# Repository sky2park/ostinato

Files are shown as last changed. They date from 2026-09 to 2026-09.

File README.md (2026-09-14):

# Ostinato

[🇺🇸 English](docs/README.en.md)




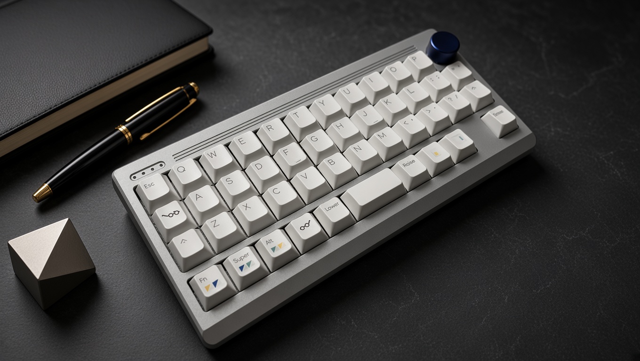
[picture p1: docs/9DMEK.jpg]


처음부터 직접 설계한 40% 오소리니어 기계식 키보드입니다.

Ostinato는 커스텀 PCB, 알루미늄 케이스, 가스켓 마운트 플레이트, 로터리 엔코더, RGB 상태 표시등, USB 연결을 기본으로 하는 45키 오소리니어 키보드입니다. USB 전원이 공급되는 상태에서 Bluetooth 무선 출력을 사용할 수 있습니다.

이 프로젝트에는 PCB와 케이스부터 QMK/Vial 펌웨어와 ESP32-C3 Bluetooth 컨트롤러까지 전체 하드웨어 및 펌웨어 설계가 포함되어 있습니다.

---

## 주요 기능

- 40% 오소리니어 레이아웃
- 45키
- MX 호환 스위치
- QMK 펌웨어
- Vial 지원
- USB 및 Bluetooth 연결
- ESP32-C3 기반 Bluetooth 컨트롤러 (USB 전원 필요, 배터리 없음, 단독 무선 작동 불가)
- RP2040 기반 메인 컨트롤러
- 3개의 Bluetooth 연결 슬롯
- 로터리 엔코더
- SK6812MINI RGB LED
- 전용 Bluetooth 상태 표시등
- 레이어 상태 표시
- 가스켓 마운트 플레이트
- 커스텀 알루미늄 상판 케이스
- MJF PA12S 나일론 하판 케이스
- SUS304 스테인리스 스틸 또는 H59 구리 합금 황동 내부 웨이트

---

## 사양

| 항목 | 내용 |
|---|---|
| 레이아웃 | 40% 오소리니어 |
| 키 수 | 45 |
| 메인 MCU | RP2040 |
| Bluetooth MCU | ESP32-C3 |
| 펌웨어 | QMK |
| 키맵 설정 | Vial |
| 연결 방식 | USB 기본 / Bluetooth 무선 출력 (USB 전원 필요) |
| 전원 공급 | USB |
| 배터리 | 없음 |
| Bluetooth 슬롯 | 3 |
| 스위치 종류 | MX 호환 |
| RGB LED | SK6812MINI (4개) |
| 로터리 엔코더 | 1개 |
| 마운팅 | 가스켓 마운트 (Poron) |
| 플레이트 | PC |
| 상판 케이스 | 6061 알루미늄 |
| 하판 케이스 | MJF PA12S 나일론 |
| 내부 웨이트 | SUS304 스테인리스 스틸 또는 H59 구리 합금 황동 |

---

## 레이아웃

Ostinato는 45키의 컴팩트한 40% 오소리니어 레이아웃을 사용합니다.

작은 크기를 유지하면서 풀사이즈 키보드에 준하는 기능을 제공할 수 있도록 여러 레이어를 중심으로 설계되었습니다.

### 레이어

펌웨어에는 다음과 같은 주요 레이어가 포함되어 있습니다:

- **기본**
- **내비게이션**
- **숫자 / 기호**
- **기능**
- **게이밍**
- **게이밍+**
- **게이밍 내비게이션**

추가 레이어와 키 할당은 Vial을 통해 설정할 수 있습니다.

---

## 연결

Ostinato는 USB 연결을 기본으로 사용하며, USB 전원이 공급되는 상태에서 Bluetooth 무선 출력을 지원합니다.

> **⚠️ 전원 및 Bluetooth 사용 안내**
>
> Ostinato는 배터리를 내장하지 않은 키보드입니다. 키보드의 작동과 Bluetooth 사용을 위해 USB 케이블을 연결해야 합니다.
>
> USB 케이블을 연결하지 않은 상태에서는 키보드 단독으로 Bluetooth를 사용할 수 없습니다.

RP2040은 키보드의 주요 기능을 담당하며, ESP32-C3 모듈이 Bluetooth 연결을 제공합니다.

### USB

USB 모드에서는 일반적인 USB HID 키보드로 동작합니다.

### Bluetooth

키보드는 3개의 Bluetooth 연결 슬롯을 지원합니다:

- **Bluetooth 1**
- **Bluetooth 2**
- **Bluetooth 3**

활성 Bluetooth 슬롯은 키보드에서 직접 선택할 수 있습니다. 펌웨어는 UART를 통해 ESP32-C3와 통신하며 Bluetooth 연결 상태와 슬롯 선택을 제어합니다.

Bluetooth를 사용하더라도 USB 케이블을 통한 전원 공급이 필요합니다. 배터리가 없으므로 USB 전원 없이 Bluetooth만으로 작동할 수 없습니다.

---

## Bluetooth 상태

RGB LED는 Bluetooth 상태를 시각적으로 표시하는 데 사용됩니다. 각 Bluetooth 슬롯에는 전용 상태 표시등이 있습니다.

표시등은 다음과 같은 상태를 구분합니다:

- 광고(Advertising)
- 연결됨
- 페어링
- 오류 / 사용 불가

이를 통해 호스트 기기를 사용하지 않고도 현재 Bluetooth 연결 상태를 확인할 수 있습니다.

---

## RGB 표시등

Ostinato는 4개의 SK6812MINI RGB LED를 사용합니다. 이 LED는 장식용 백라이트가 아니라 기능적인 상태 표시등으로 사용됩니다.

### Bluetooth 표시등

3개의 LED가 각각 3개의 Bluetooth 슬롯 상태를 표시합니다.

### 레이어 표시등

나머지 1개의 LED는 레이어/상태 표시용으로 사용됩니다. 펌웨어는 이 표시등을 특수 키보드 기능의 상태를 표시하는 데에도 사용할 수 있습니다.

---

## 로터리 엔코더

Ostinato에는 추가 입력을 위한 로터리 엔코더가 포함되어 있습니다.

엔코더는 QMK와 Vial을 통해 설정할 수 있으며, 활성 레이어에 따라 서로 다른 기능을 할당할 수 있습니다.

---

## 아키텍처 및 설계 철학

Ostinato의 목표는 컴팩트한 오소리니어 레이아웃에 일반적으로 대형 키보드에서 제공되는 기능을 결합하는 것입니다.

하나의 무선 컨트롤러에 모든 기능을 의존하는 대신, 메인 키보드 컨트롤러와 Bluetooth 컨트롤러를 분리하는 구조로 설계했습니다:

```text
       ┌───────────────┐
       │    RP2040     │
       │ Main Keyboard │
       │  Controller   │
       └───────┬───────┘
               │
              UART
               │
       ┌───────▼───────┐
       │   ESP32-C3    │
       │   Bluetooth   │
       │  Controller   │
       └───────────────┘
```

이 아키텍처를 통해 RP2040은 핵심 키보드 동작(매트릭스 스캔, 조명, Vial 설정)을 담당하고, ESP32-C3는 Bluetooth 연결 스택을 담당합니다.

---

## 펌웨어

Ostinato 펌웨어는 QMK 및 Vial-QMK를 기반으로 하며 **GNU General Public License v2.0 (GPL-2.0)**에 따라 라이선스가 부여됩니다.

```text
firmware/
├── esp32-c3/
├── qmk/
│   └── ostinato/
└── vial/
    └── ostinato/
```

- **QMK 펌웨어**: 매트릭스 스캔, 키맵 및 레이어, 커스텀 키코드, 로터리 엔코더, RGB 상태 표시등, USB 출력, ESP32-C3와의 UART 통신을 담당합니다.
- **ESP32-C3 펌웨어**: Bluetooth 프로파일 관리, 연결 슬롯, 무선 HID 출력을 담당합니다.

### 커스텀 키코드

Ostinato는 출력 및 연결 제어를 위해 다음과 같은 커스텀 키코드를 정의합니다:

- `OUT_USB`
- `OUT_BT1`
- `OUT_BT2`
- `OUT_BT3`
- `BT_CLR`

이 키코드를 사용하면 USB와 페어링된 3개의 Bluetooth 기기 사이를 즉시 전환할 수 있습니다.

---

## 하드웨어

PCB, 케이스, 플레이트 및 관련 CAD 파일을 포함한 Ostinato 하드웨어 설계 파일은 **Creative Commons Attribution-NonCommercial 4.0 International (CC BY-NC 4.0)** 라이선스에 따라 제공됩니다.

개인적 및 비상업적 사용은 허용됩니다.

상업적 사용에는 저작자의 사전 허가가 필요합니다.

하드웨어는 다음과 같은 모듈형 커스텀 보드로 구성됩니다:

```text
pcb/
├── main-module/
├── led_module/
└── knob-module/
```

- **메인 모듈**: RP2040 컨트롤러, ESP32-C3, 다이오드 매트릭스 및 전원 회로를 탑재합니다.
- **LED 모듈**: 슬롯 및 레이어 상태 표시를 위한 4개의 SK6812MINI 어드레서블 RGB LED를 탑재합니다.
- **노브 모듈**: 로터리 엔코더와 브레이크아웃 인터페이스를 탑재합니다.

### 케이스 및 플레이트

- **상판 케이스**: CNC 가공 6061 알루미늄
- **하판 케이스**: MJF 3D 프린팅 PA12S 나일론
- **내부 웨이트**: 레이저 절단 SUS304 스테인리스 스틸 또는 H59 구리 합금 황동
- **마운팅**: PC 플레이트를 분리하는 커스텀 Poron 가스켓 스트립을 사용하여 부드럽고 공명감 있는 바텀아웃을 구현합니다.

> **제조 및 공차 관련 참고사항**  
> 모든 케이스 부품(상판 케이스, 하판 케이스, 내부 웨이트)은 **JLCCNC** 및 **JLC3DP**를 통해 프로토타입을 제작하고 검증했습니다. 제조업체와 제작 방식에 따라 공차와 표면 마감이 달라질 수 있으므로, 다른 업체에서 제작한 부품은 테스트되지 않았으며 조립 또는 치수 호환성 문제가 발생할 수 있습니다.

플레이트 절단 프로파일은 `plate/` 아래에 DXF 형식으로 제공됩니다:
- `design.dxf`
- `plate.dxf`

---

## 제조 및 주문 가이드

모든 부품은 특정 제작 업체를 기준으로 설계하고 검증했습니다. Ostinato를 제작할 계획이라면 아래 주문 가이드를 참고하세요.

### 개요

| 부품 | 소스 파일 | 권장 서비스 | 공정 / 재료 사양 |
|---|---|---|---|
| **Top Case** | `case/top.step`<br>`case/top_theads.pdf` (Thread/tapping drawing) | JLCCNC | CNC Machining / 6061 Aluminum (Sandblasted / Anodized) |
| **Bottom Case** | `case/bottom.step` | JLC3DP | 3D Printing / MJF Nylon (PA12S) |
| **Internal Weight** | `case/weight.step` | JLCCNC | CNC or Sheet Metal / SUS304 Stainless steel or H59 Brass |
| **Plate** | `plate/plate.dxf` | Laser cutting service | Laser Cut / 1.5mm Polycarbonate (PC) |
| **PCBs** | `pcb/*/gerber/` | JLCPCB | FR-4 / 1.6mm (or 1.2mm depending on build) |

---

### 부품 상세 및 주문 방법

#### 1. 케이스 및 웨이트 (JLCCNC / JLC3DP)
- **Top Case**:
  - **File**: `case/top.step`
  - **나사산 도면**: `case/top_theads.pdf` (탭 가공을 주문할 때 이 2D 도면을 함께 첨부하세요)
  - **서비스**: [JLCCNC](https://jlccnc.com/) (CNC 가공)
  - **재료**: 6061 알루미늄
  - **표면 처리**: 비드 블라스트(샌드블라스트 #150 또는 #180) + 아노다이징(원하는 색상)
- **Bottom Case**:
  - **File**: `case/bottom.step`
  - **Service**: [JLC3DP](https://jlc3dp.com/) (3D Printing)
  - **기술**: MJF (Multi Jet Fusion)
  - **재료**: PA12S 나일론 (검정/염색)
- **Internal Weight**:
  - **File**: `case/weight.step`
  - **Service**: [JLCCNC](https://jlccnc.com/)
  - **재료**: SUS304 스테인리스 스틸 (헤어라인 / 샌드블라스트) 또는 H59 황동

> ⚠️ **중요 공차 경고**:  
> CAD 모델, 공차 및 조립 여유 치수는 **JLCCNC** 및 **JLC3DP**를 기준으로 조정하고 검증했습니다. 다른 업체나 다른 제작 방식은 테스트되지 않았으며, 부적절한 조립, 수축 편차 또는 조립 문제가 발생할 수 있습니다.

#### 2. 스위치 플레이트
- **File**: `plate/plate.dxf`
- **재료**: 1.5mm 폴리카보네이트 (PC)
- **서비스**: 정밀 레이저 절단이 가능한 업체 (예: JLCCNC 판재 절단 또는 현지 레이저 절단 업체).

#### 3. PCB
- **Paths**:
  - `pcb/main-module/`
  - `pcb/led_module/`
  - `pcb/knob-module/`
- **Service**: [JLCPCB](https://jlcpcb.com/)
- **Ordering Recommendations**:
  - Upload the Gerber zip files along with the **BOM and CPL files** from each folder to order the **PCB Assembly (SMT)** service.
  - **PCBA Settings**:
    - **Assembly Side**: Select **`Bottom Side`** for all three modules.
    - **PCBA Type**:
      - `main-module`: Must be set to **`Standard`** due to assembly constraints of the ESP32-C3 module (bottom pad soldering).
      - `led_module` & `knob-module`: Select **`Economy`**.
  - ⚠️ **Note**: The **EC11 rotary encoder** on the `knob-module` is not covered by the SMT service; source it separately and solder it by hand (through-hole soldering).
  
#### 4. 추가 기성 부품 (하드웨어 및 구매)

이러한 표준 하드웨어 부품과 구성품은 별도 제작품이 아니며, 일반 하드웨어 마켓플레이스(예: AliExpress)나 커스텀 키보드 판매처에서 구매할 수 있습니다.

> **참고**: 아래 링크는 제가 프로토타입 제작에 실제로 사용한 동일한 제품 목록과 구매처입니다. 참고용으로만 제공하며, 사양에 맞는 동등한 부품이라면 어떤 제품을 사용해도 됩니다.

| 품목 | 사양 | 수량 | 참고 링크 | 비고 |
|---|---|---|---|---|
| **Poron Gasket Strips** | 20mm (L) × 3mm (W) × 2mm (T) | 8 | [AliExpress](https://ko.aliexpress.com/item/1005005713921230.html) | Mounts to plate tabs / case edges |
| **FPC Ribbon Cable** | 0.5mm pitch, 6-pin, **Reverse (Type B)**, 10–15cm | 2 | [AliExpress](https://aliexpress.com/item/1005007862185591.html) | Connects main module to LED / knob modules |
| **Rotary Encoder** | EC11 rotary encoder, **15mm shaft height** | 1 | [AliExpress](https://aliexpress.com/item/1005009120433387.html) | Hand-soldered onto `knob-module` |
| **Encoder Knob** | Compatible with EC11 shaft **20 x 13 x 6mm** | 1 | [AliExpress](https://aliexpress.com/item/1005007339301144.html) | Fits selected rotary encoder |
| **Unified Daughterboard S1 & Cable** | Unified Daughterboard (UDB) S1 with Molex cable | 1 | [Vendor Link](https://keebd.com/products/unified-daughterboards?variant=45606739411096) | Available via various keyboard vendor stores (e.g., CannonKeys, Swagkeys, etc.)
| **Light Guides** | Acrylic light pipe / guide **1.5-2.2 or 2.9-3.0** | 4 | [AliExpress](https://aliexpress.com/item/1005005231503928.html) | Diffuses status LEDs |
| **Heat-set Insert** | M2 × L3mm × OD 3.2mm | 4 | [AliExpress](https://aliexpress.com/item/1005006472641726.html) | Case / module mounting |
| **Heat-set Insert** | M3 × L4mm × OD 4.2mm | 6 | [AliExpress](https://aliexpress.com/item/1005006472641726.html) | Weight / case and Weight / UDB mounting |
| **Screw** | M2 × 4mm | 4 | [AliExpress](https://aliexpress.com/item/1005005270702287.html) | Internal module mounting |
| **Screw** | M2.5 × 8mm | 4 | [AliExpress](https://aliexpress.com/item/1005005270702287.html) | Case assembly |
| **Screw** | M3 × 5mm | 6 | [AliExpress](https://aliexpress.com/item/1005005270702287.html) | Internal weight / UDB fastening |

---

## 빌드 가이드

🚧 상세 빌드 가이드 영상은 현재 준비 중입니다.

---

## 저장소 구조

```text
ostinato/
├── case/             # CAD and step/stl files for case parts
├── firmware/
│   ├── esp32-c3/     # ESP-IDF / Arduino BT firmware
│   ├── qmk/          # QMK source and keyboard rules
│   │   └── ostinato/
│   └── vial/         # Vial configuration & keymap files
│       └── ostinato/
├── pcb/
│   ├── main-module/  # Schematic, KiCad layouts, and Gerber files
│   ├── led_module/
│   └── knob-module/
├── plate/
│   ├── design.dxf
│   └── plate.dxf
└── README.md
```

---

## 상태

Ostinato는 현재 개발이 진행 중인 커스텀 하드웨어 프로젝트입니다. 실제 리비전을 테스트하는 과정에서 회로도, Gerber 파일 및 펌웨어 구현이 호환성을 깨뜨리는 형태로 변경될 수 있습니다.

---

## 크레딧

**sky2park**가 설계 및 개발했습니다.

- [QMK Firmware](https://qmk.fm/)
- [Vial](https://get.vial.today/)
- Raspberry Pi RP2040 & Espressif ESP32-C3

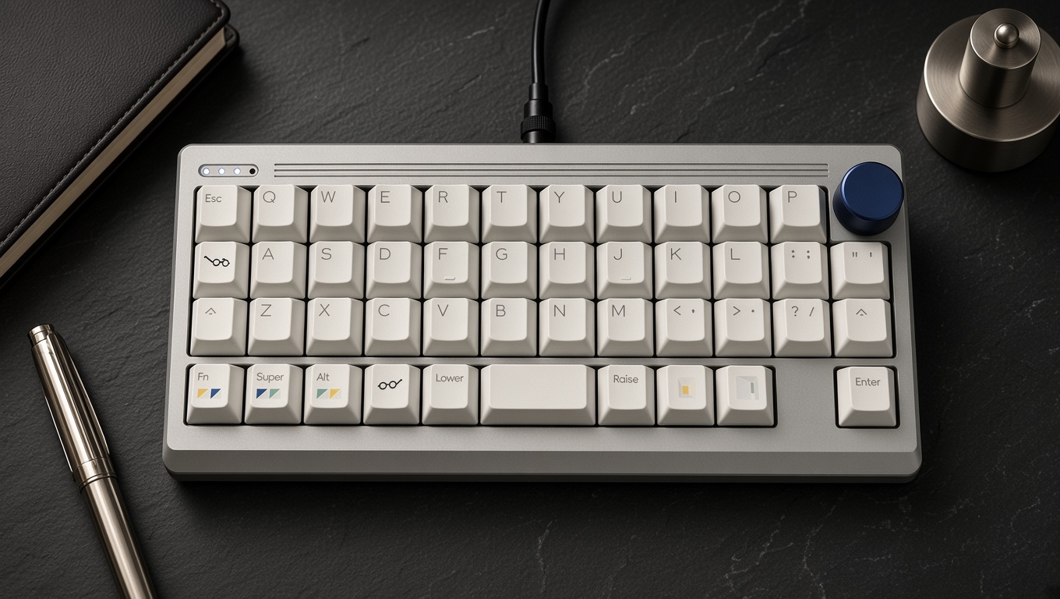
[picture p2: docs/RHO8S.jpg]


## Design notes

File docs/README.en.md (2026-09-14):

# Ostinato

[🇰🇷 한국어](../README.md)




Ostinato Keyboard

A custom 40% ortholinear mechanical keyboard designed from the ground up.

Ostinato is a custom 45-key ortholinear keyboard featuring a custom PCB, aluminum case, gasket-mounted plate, rotary encoder, RGB status indicators, and USB connectivity with Bluetooth wireless output when powered via USB.

The project includes the complete hardware and firmware design, from the PCB and case to the QMK/Vial firmware and ESP32-C3 Bluetooth controller.

---

## Features

- 40% ortholinear layout
- 45 keys
- MX-compatible switches
- QMK firmware
- Vial support
- USB and Bluetooth connectivity
- ESP32-C3-based Bluetooth controller (USB power required; no battery; standalone wireless operation is not supported)
- RP2040-based main controller
- Three Bluetooth connection slots
- Rotary encoder
- SK6812MINI RGB LEDs
- Dedicated Bluetooth status indicators
- Layer status indication
- Gasket-mounted plate
- Custom aluminum top case
- MJF PA12S nylon bottom case
- Stainless steel or H59 Copper alloy Brass internal weight

---

## Specifications

| Specification | Details |
|---|---|
| Layout | 40% Ortholinear |
| Keys | 45 |
| Main MCU | RP2040 |
| Bluetooth MCU | ESP32-C3 |
| Firmware | QMK |
| Keymap Configuration | Vial |
| Connectivity | USB (primary) / Bluetooth wireless output (USB power required) |
| Power | USB |
| Battery | None |
| Bluetooth Slots | 3 |
| Switch Type | MX-compatible |
| RGB LEDs | SK6812MINI (4x) |
| Rotary Encoder | 1 |
| Mounting | Gasket mount (Poron) |
| Plate | PC |
| Top Case | 6061 Aluminum |
| Bottom Case | MJF PA12S Nylon |
| Internal Weight | SUS304 Stainless steel or H59 Copper alloy Brass |

---

## Layout

Ostinato uses a compact 40% ortholinear layout with 45 keys.

The layout is designed around multiple layers to provide the functionality of a full-size keyboard while maintaining a small footprint.

### Layers

The firmware includes the following primary layers:

- **Base**
- **Navigation**
- **Number / Symbol**
- **Function**
- **Gaming**
- **Gaming+**
- **Gaming Navigation**

Additional layers and key assignments can be configured through Vial.

---

## Connectivity

Ostinato is primarily designed to operate with a USB connection. Bluetooth wireless output is available when the keyboard is powered via USB.

> **⚠️ Power and Bluetooth Notice**
>
> Ostinato does not have a built-in battery. A USB cable must be connected to power the keyboard.
>
> Bluetooth can only be used while USB power is connected. Standalone Bluetooth operation without a USB connection is not supported.

### USB

In USB mode, Ostinato operates as a standard USB HID keyboard. The keyboard is powered through the USB connection, and all primary functions are available.

### Bluetooth

In Bluetooth mode, the ESP32-C3 transmits key inputs wirelessly to a paired host device.

The keyboard supports three Bluetooth connection slots:

- Bluetooth 1
- Bluetooth 2
- Bluetooth 3

The active Bluetooth slot can be selected directly from the keyboard. The firmware communicates with the ESP32-C3 over UART to control Bluetooth connection status and slot selection.

**Note:** USB power is required even when using Bluetooth. Ostinato has no battery and cannot operate as a standalone wireless keyboard without a USB connection.

### USB

In USB mode, the keyboard operates as a standard USB HID keyboard.

### Bluetooth

The keyboard supports three Bluetooth connection slots:

- **Bluetooth 1**
- **Bluetooth 2**
- **Bluetooth 3**

The active Bluetooth slot can be selected directly from the keyboard. The firmware communicates with the ESP32-C3 over UART to control Bluetooth connection state and slot selection.

---

## Bluetooth Status

The RGB LEDs are used to provide visual feedback for Bluetooth status. Each Bluetooth slot has a dedicated status indicator.

The indicators distinguish between states such as:

- Advertising
- Connected
- Pairing
- Error / unavailable

This allows the current Bluetooth connection state to be checked without using a host device.

---

## RGB Indicators

Ostinato uses four SK6812MINI RGB LEDs. The LEDs are used as functional status indicators rather than decorative backlighting.

### Bluetooth Indicators

Three LEDs indicate the status of the three Bluetooth slots.

### Layer Indicator

The remaining LED is used for layer/status indication. The firmware can also use the indicator to display the state of special keyboard functions.

---

## Rotary Encoder

Ostinato includes a rotary encoder for additional input.

The encoder can be configured through QMK and Vial and can be assigned different functions depending on the active layer.

---

## Architecture & Design Philosophy

The goal of Ostinato is to combine a compact ortholinear layout with functionality normally associated with larger keyboards.

Rather than relying on a single wireless controller, the design separates the main keyboard controller and Bluetooth controller:

```text
       ┌───────────────┐
       │    RP2040     │
       │ Main Keyboard │
       │  Controller   │
       └───────┬───────┘
               │
              UART
               │
       ┌───────▼───────┐
       │   ESP32-C3    │
       │   Bluetooth   │
       │  Controller   │
       └───────────────┘
```

This architecture allows the RP2040 to remain responsible for the core keyboard operations (matrix scanning, lighting, Vial configuration) while the ESP32-C3 handles the Bluetooth connectivity stack.

---

## Firmware

The Ostinato firmware is based on QMK and Vial-QMK and is licensed under the **GNU General Public License v2.0 (GPL-2.0)**.

```text
firmware/
├── esp32-c3/
├── qmk/
│   └── ostinato/
└── vial/
    └── ostinato/
```

- **QMK Firmware**: Handles matrix scanning, keymaps and layers, custom keycodes, rotary encoder, RGB status indicators, USB output, and UART communication with the ESP32-C3.
- **ESP32-C3 Firmware**: Handles Bluetooth profile management, connection slots, and wireless HID output.

### Custom Keycodes

Ostinato defines custom keycodes for output and connection control:

- `OUT_USB`
- `OUT_BT1`
- `OUT_BT2`
- `OUT_BT3`
- `BT_CLR`

These keycodes allow switching between USB and the three paired Bluetooth devices on the fly.

---

## Hardware

The Ostinato hardware design files, including PCB, case, plate, and related CAD files, are licensed under the **Creative Commons Attribution-NonCommercial 4.0 International (CC BY-NC 4.0)** license.

Personal and non-commercial use is permitted.

Commercial use requires prior permission from the author.

The hardware is divided into modular custom boards:

```text
pcb/
├── main-module/
├── led_module/
└── knob-module/
```

- **Main Module**: Hosts the RP2040 controller, ESP32-C3, diode matrix, and power regulation.
- **LED Module**: Contains four SK6812MINI addressable RGB LEDs for slot and layer visualization.
- **Knob Module**: Houses the rotary encoder and its breakout interface.

### Case & Plate

- **Top Case**: CNC-machined 6061 aluminum
- **Bottom Case**: MJF 3D-printed PA12S nylon
- **Internal Weight**: Laser-cut SUS304 Stainless steel or H59 Copper alloy Brass
- **Mounting**: Custom Poron gasket strips isolating the PC plate for a soft, resonant bottom-out.

> **Note on Manufacturing & Tolerances**  
> All case components (top case, bottom case, and internal weight) were prototyped and verified using **JLCCNC** and **JLC3DP**. Because tolerances and finishing can vary across different manufacturers and fabrication methods, parts produced through other vendors have not been tested and may have fitment/assembly issues.

Plate cutting profiles are provided in DXF format under `plate/`:
- `design.dxf`
- `plate.dxf`

---

## Manufacturing & Ordering Guide

All components have been designed and verified with specific fabrication vendors. If you plan to build Ostinato, follow the guidelines below for ordering parts.

### Overview

| Part | Source Files | Recommended Service | Process / Material Specs |
|---|---|---|---|
| **Top Case** | `case/top.step`<br>`case/top_theads.pdf` (Thread/tapping drawing) | JLCCNC | CNC Machining / 6061 Aluminum (Sandblasted / Anodized) |
| **Bottom Case** | `case/bottom.step` | JLC3DP | 3D Printing / MJF Nylon (PA12S) |
| **Internal Weight** | `case/weight.step` | JLCCNC | CNC or Sheet Metal / SUS304 Stainless steel or H59 Brass |
| **Plate** | `plate/plate.dxf` | Laser cutting service | Laser Cut / 1.5mm Polycarbonate (PC) |
| **PCBs** | `pcb/*/gerber/` | JLCPCB | FR-4 / 1.6mm (or 1.2mm depending on build) |

---

### Component Details & Ordering Instructions

#### 1. Case & Weight (JLCCNC / JLC3DP)
- **Top Case**:
  - **File**: `case/top.step`
  - **Thread Drawing**: `case/top_theads.pdf` (Attach this 2D drawing when ordering for threaded hole tapping)
  - **Service**: [JLCCNC](https://jlccnc.com/) (CNC Machining)
  - **Material**: 6061 Aluminum
  - **Finish**: Bead blasted (Sandblasting #150 or #180) + Anodized (Color of your choice)
- **Bottom Case**:
  - **File**: `case/bottom.step`
  - **Service**: [JLC3DP](https://jlc3dp.com/) (3D Printing)
  - **Technology**: MJF (Multi Jet Fusion)
  - **Material**: PA12S Nylon (Black/Dyed)
- **Internal Weight**:
  - **File**: `case/weight.step`
  - **Service**: [JLCCNC](https://jlccnc.com/)
  - **Material**: SUS304 Stainless steel (Brushed / Sandblasted) or H59 Brass

> ⚠️ **Important Tolerance Warning**:  
> The CAD models, tolerances, and fitment clearances are tuned and verified specifically for **JLCCNC** and **JLC3DP**. Fabrication via other vendors or processes has not been tested and may result in improper fitment, shrinkage variance, or assembly issues.

#### 2. Switch Plate
- **File**: `plate/plate.dxf`
- **Material**: 1.5mm Polycarbonate (PC)
- **Service**: Any precision laser-cutting vendor (e.g., JLCCNC sheet cutting or local laser cutting services).

#### 3. PCBs
- **Paths**:
  - `pcb/main-module/`
  - `pcb/led_module/`
  - `pcb/knob-module/`
- **Service**: [JLCPCB](https://jlcpcb.com/)
- **Ordering Recommendations**:
  - Upload the Gerber zip files along with the **BOM and CPL files** from each folder to order the **PCB Assembly (SMT)** service.
  - **PCBA Settings**:
    - **Assembly Side**: Select **`Bottom Side`** for all three modules.
    - **PCBA Type**:
      - `main-module`: Must be set to **`Standard`** due to assembly constraints of the ESP32-C3 module (bottom pad soldering).
      - `led_module` & `knob-module`: Select **`Economy`**.
  - ⚠️ **Note**: The **EC11 rotary encoder** on the `knob-module` is not covered by the SMT service; source it separately and solder it by hand (through-hole soldering).
  
#### 4. Additional Off-the-Shelf Parts (Hardware & Sourcing)

These standard hardware parts and components are not custom-fabricated and can be sourced from general hardware marketplaces (e.g., AliExpress) or custom keyboard vendors.

> **Note**: The links below reflect the exact listings and sources I used for my prototype build. They are provided solely for reference—any equivalent parts matching the specifications will work.

| Item | Specification | Qty | Reference Link | Notes |
|---|---|---|---|---|
| **Poron Gasket Strips** | 20mm (L) × 3mm (W) × 2mm (T) | 8 | [AliExpress](https://ko.aliexpress.com/item/1005005713921230.html) | Mounts to plate tabs / case edges |
| **FPC Ribbon Cable** | 0.5mm pitch, 6-pin, **Reverse (Type B)**, 10–15cm | 2 | [AliExpress](https://aliexpress.com/item/1005007862185591.html) | Connects main module to LED / knob modules |
| **Rotary Encoder** | EC11 rotary encoder, **15mm shaft height** | 1 | [AliExpress](https://aliexpress.com/item/1005009120433387.html) | Hand-soldered onto `knob-module` |
| **Encoder Knob** | Compatible with EC11 shaft **20 x 13 x 6mm** | 1 | [AliExpress](https://aliexpress.com/item/1005007339301144.html) | Fits selected rotary encoder |
| **Unified Daughterboard S1 & Cable** | Unified Daughterboard (UDB) S1 with Molex cable | 1 | [Vendor Link](https://keebd.com/products/unified-daughterboards?variant=45606739411096) | Available via various keyboard vendor stores (e.g., CannonKeys, Swagkeys, etc.)
| **Light Guides** | Acrylic light pipe / guide **1.5-2.2 or 2.9-3.0** | 4 | [AliExpress](https://aliexpress.com/item/1005005231503928.html) | Diffuses status LEDs |
| **Heat-set Insert** | M2 × L3mm × OD 3.2mm | 4 | [AliExpress](https://aliexpress.com/item/1005006472641726.html) | Case / module mounting |
| **Heat-set Insert** | M3 × L4mm × OD 4.2mm | 6 | [AliExpress](https://aliexpress.com/item/1005006472641726.html) | Weight / case and Weight / UDB mounting |
| **Screw** | M2 × 4mm | 4 | [AliExpress](https://aliexpress.com/item/1005005270702287.html) | Internal module mounting |
| **Screw** | M2.5 × 8mm | 4 | [AliExpress](https://aliexpress.com/item/1005005270702287.html) | Case assembly |
| **Screw** | M3 × 5mm | 6 | [AliExpress](https://aliexpress.com/item/1005005270702287.html) | Internal weight / UDB fastening |

---

## Build Guide

A detailed build guide video is currently in preparation
and will be added here once available.

---

## Repository Structure

```text
ostinato/
├── case/             # CAD and step/stl files for case parts
├── firmware/
│   ├── esp32-c3/     # ESP-IDF / Arduino BT firmware
│   ├── qmk/          # QMK source and keyboard rules
│   │   └── ostinato/
│   └── vial/         # Vial configuration & keymap files
│       └── ostinato/
├── pcb/
│   ├── main-module/  # Schematic, KiCad layouts, and Gerber files
│   ├── led_module/
│   └── knob-module/
├── plate/
│   ├── design.dxf
│   └── plate.dxf
└── README.md
```

---

## Status

Ostinato is an active custom hardware project. Schematics, gerber files, and firmware implementations may receive breaking updates as physical revisions are tested.

---

## Credits

Designed and developed by **sky2park**.

- [QMK Firmware](https://qmk.fm/)
- [Vial](https://get.vial.today/)
- Raspberry Pi RP2040 & Espressif ESP32-C3

Ostinato Keyboard

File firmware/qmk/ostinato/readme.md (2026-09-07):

# Ostinato

Ostinato

*A short description of the keyboard/project*

* Keyboard Maintainer: [sky2park](https://github.com/sky2park)
* Hardware Supported: *The PCBs, controllers supported*
* Hardware Availability: *Links to where you can find this hardware*

Make example for this keyboard (after setting up your build environment):

    make ostinato:default

Flashing example for this keyboard:

    make ostinato:default:flash

See the [build environment setup](https://docs.qmk.fm/#/getting_started_build_tools) and the [make instructions](https://docs.qmk.fm/#/getting_started_make_guide) for more information. Brand new to QMK? Start with our [Complete Newbs Guide](https://docs.qmk.fm/#/newbs).

## Bootloader

Enter the bootloader in 3 ways:

* **Bootmagic reset**: Hold down the key at (0,0) in the matrix (usually the top left key or Escape) and plug in the keyboard
* **Physical reset button**: Briefly press the button on the back of the PCB - some may have pads you must short instead
* **Keycode in layout**: Press the key mapped to `QK_BOOT` if it is available

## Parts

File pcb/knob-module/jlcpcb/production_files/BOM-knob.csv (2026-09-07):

Comment | Designator | Footprint | LCSC | Quantity
Conn_01x06 | J1 | Hirose_FH12-6S-0.5SH_1x06-1MP_P0.50mm_Horizontal | C202118 | 1
D_Small | D47 | D_SOD-123 | C81598 | 1

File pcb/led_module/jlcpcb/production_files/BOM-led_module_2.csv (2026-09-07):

Comment | Designator | Footprint | LCSC | Quantity
100nF | C1,C2,C3,C4 | C_0402_1005Metric | C1525 | 4
10uF | C5 | C_0402_1005Metric | C15525 | 1
330 | R1 | R_0402_1005Metric | C21190 | 1
Conn_01x06 | J1 | Hirose_FH12-6S-0.5SH_1x06-1MP_P0.50mm_Horizontal | C202118 | 1
SK6812MINI-E | D1,D2,D3,D4 | LED_SK6812MINI-E_3.2x2.8mm_P1.5mm_ReverseMount | C5378731 | 4

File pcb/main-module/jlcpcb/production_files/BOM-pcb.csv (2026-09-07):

Comment | Designator | Footprint | LCSC | Quantity
100nF | C1,C10,C11,C12,C13,C14,C15,C19,C20,C5,C6,C9 | C_0402_1005Metric | C1525 | 12
10k | R10,R11,R3,R6,R7 | R_0402_1005Metric | C25744 | 5
10uF | C17,C18,C7 | C_0402_1005Metric | C15525 | 3
12MHz | Y1 | Crystal_SMD_3225-4Pin_3.2x2.5mm | C9002 | 1
1k | R1,R2 | R_0402_1005Metric | C11702 | 2
1uF | C16,C4,C8 | C_0402_1005Metric | C52923 | 3
220 | R8,R9 | R_0402_1005Metric | C25091 | 2
22pF | C2,C3 | C_0402_1005Metric | C1555 | 2
27R | R4,R5 | R_0402_1005Metric | C25100 | 2
AP2112K-3.3 | U2 | SOT-23-5 | C3021085 | 1
Conn_01x06 | J3,J4 | Hirose_FH12-6S-0.5SH_1x06-1MP_P0.50mm_Horizontal | C202118 | 2
D_Small | D1,D10,D11,D12,D13,D14,D15,D16,D17,D18,D19,D2,D20,D21,D22,D23,D24,D25,D26,D27,D28,D29,D3,D30,D31,D32,D33,D34,D35,D36,D37,D38,D39,D4,D40,D41,D42,D43,D44,D45,D5,D6,D7,D8,D9 | D_SOD-123 | C81598 | 45
ESP32-C3-MINI-1 | U4 | ESP32-C3-MINI-1 | C2838502 | 1
Molex - 1.00mm 4 Pin | J1,J2 | Molex_Pico-EZmate_78171-0004_1x04-1MP_P1.20mm_Vertical | C588524 | 2
RP2040 | U3 | RP2040-QFN-56 | C2040 | 1
SW_Push | SW_ESP_BOOTSEL1,SW_ESP_RESET1,SW_RP_BOOTSEL1,SW_RP_RESET1 | SW_SPST_TS-1088-xR020 | C720477 | 4
W25Q128JVS | U1 | SOIC-8_5.3x5.3mm_P1.27mm | C97521 | 1

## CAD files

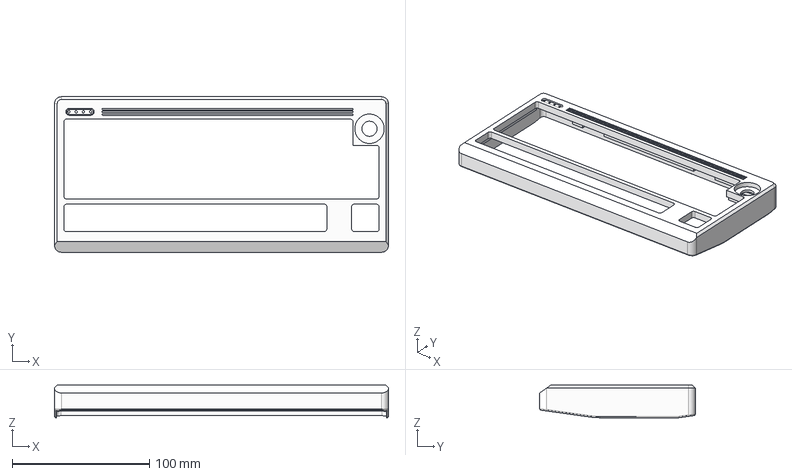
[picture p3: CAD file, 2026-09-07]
case/top.step
243.2 x 113.3 x 23.7 mm

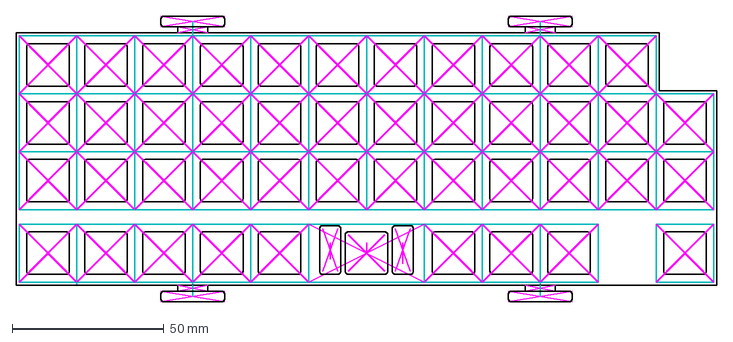
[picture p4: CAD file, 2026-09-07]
plate/design.dxf
230.6 x 94.0 mm

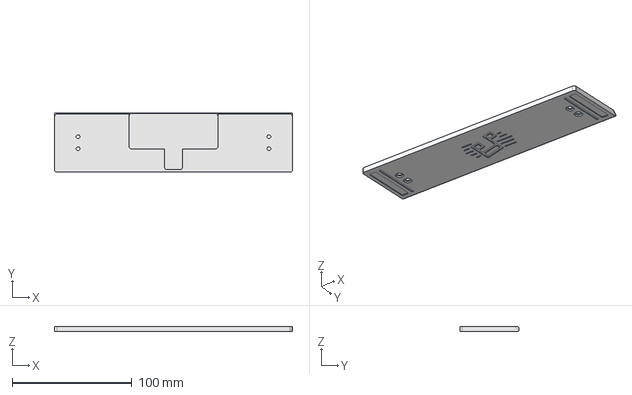
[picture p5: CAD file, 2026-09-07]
case/weight.step
199.0 x 49.7 x 4.00 mm

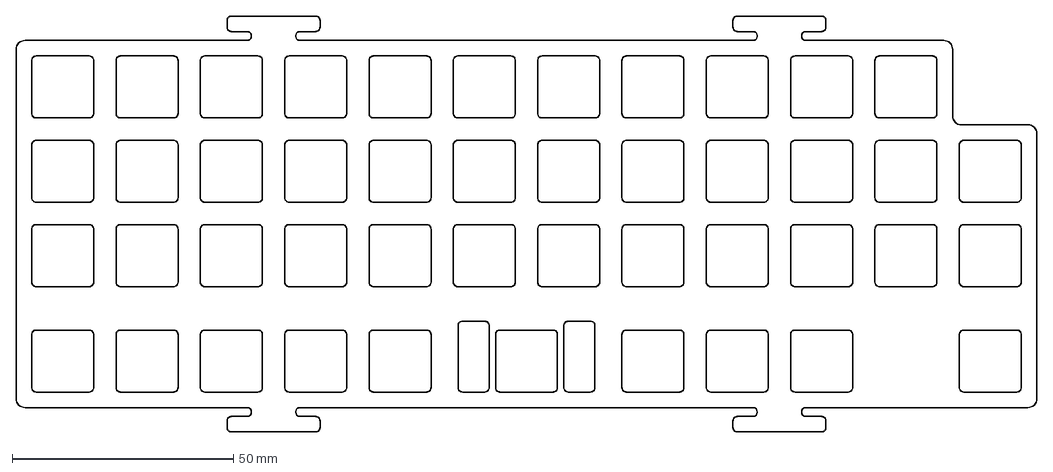
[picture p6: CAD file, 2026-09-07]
plate/plate.dxf
230.6 x 94.0 mm

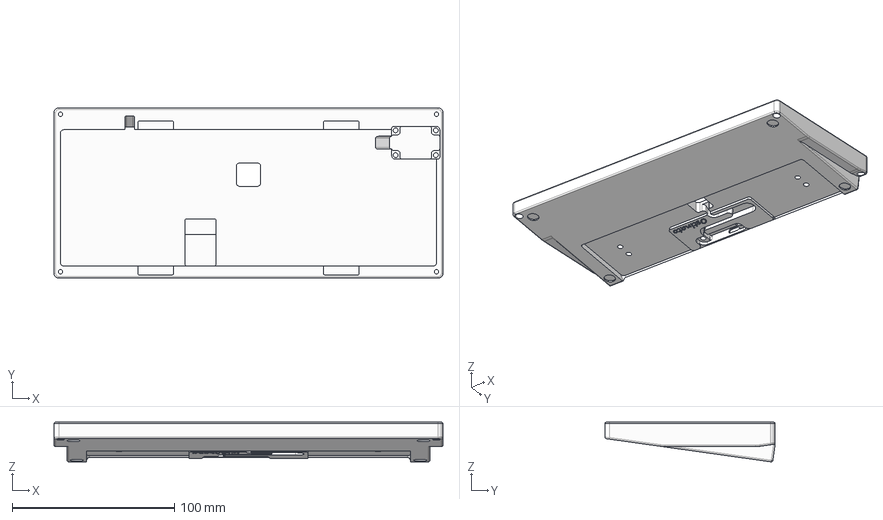
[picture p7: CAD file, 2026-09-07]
case/bottom.step
239.6 x 105.0 x 24.5 mm

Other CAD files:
case/f3d/bottom.f3d
case/f3d/top.f3d
case/f3d/weight.f3d

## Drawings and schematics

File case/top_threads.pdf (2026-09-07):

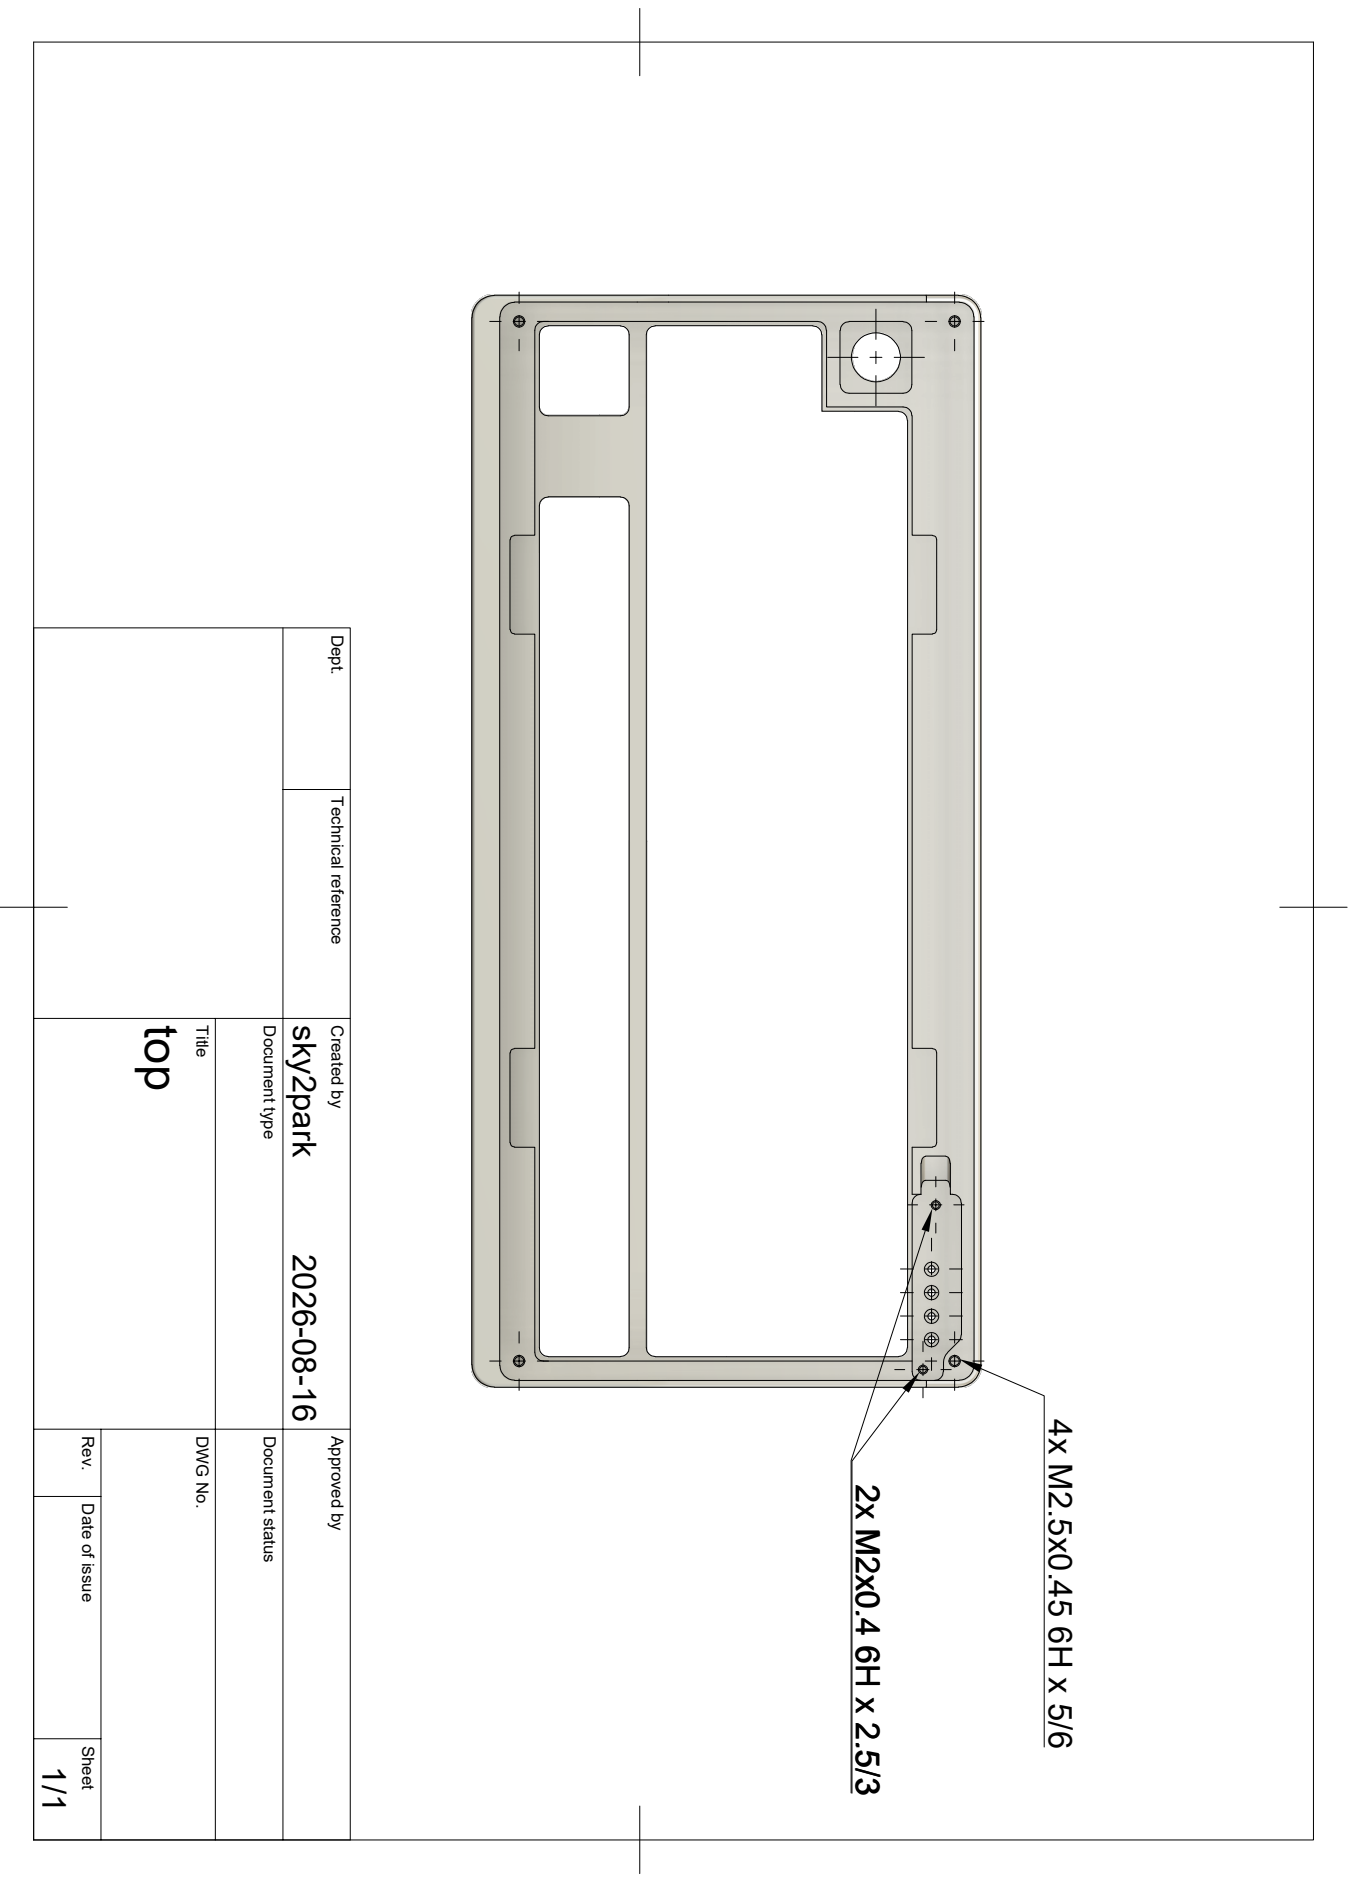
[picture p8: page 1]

Dept. Technical reference Created by Approved by Title DWG No. Document type Document status Rev. Date of issue Sheet 2026-08-16 1/1 top sky2park 2x M2x0.4 6H x 2.5/3 4x M2.5x0.45 6H x 5/6

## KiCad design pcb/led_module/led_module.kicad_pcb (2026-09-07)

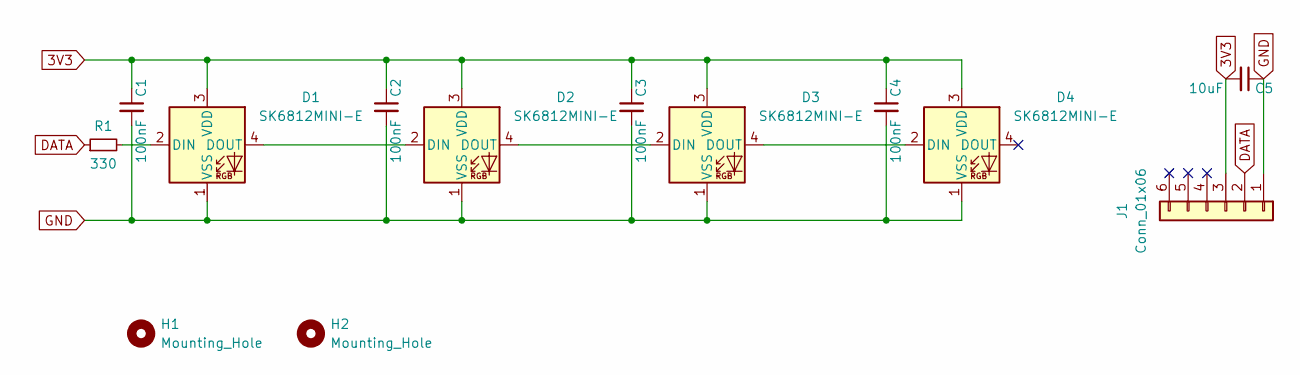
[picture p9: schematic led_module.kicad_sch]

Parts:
C1, C2, C3, C4: 100nF; C_0402_1005Metric; LCSC C66501
C5: 10uF; C_0402_1005Metric; LCSC C66501
D1, D2, D3, D4: SK6812MINI-E; LED_SK6812MINI-E_3.2x2.8mm_P1.5mm_ReverseMount
H1, H2: Mounting_Hole; Standoff_M2x6mm
J1: Conn_01x06; Hirose_FH12-6S-0.5SH_1x06-1MP_P0.50mm_Horizontal
R1: 330; R_0402_1005Metric; LCSC C21190

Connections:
3V3: C1.1, C2.1, C3.1, C4.1, C5.2, D1.3 (VDD), D2.3 (VDD), D3.3 (VDD), D4.3 (VDD), J1.3
DATA: J1.2, R1.1
GND: C1.2, C2.2, C3.2, C4.2, C5.1, D1.1 (VSS), D2.1 (VSS), D3.1 (VSS), D4.1 (VSS), J1.1
unnamed: D1.2 (DIN), R1.2
unnamed: D1.4 (DOUT), D2.2 (DIN)
unnamed: D2.4 (DOUT), D3.2 (DIN)
unnamed: D3.4 (DOUT), D4.2 (DIN)

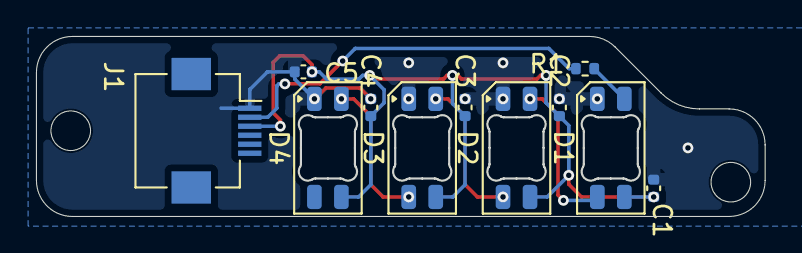
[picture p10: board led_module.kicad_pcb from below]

Board: 2 copper layers, 40.5 x 10.0 mm, 13 parts (11 on the bottom side), 7 nets.

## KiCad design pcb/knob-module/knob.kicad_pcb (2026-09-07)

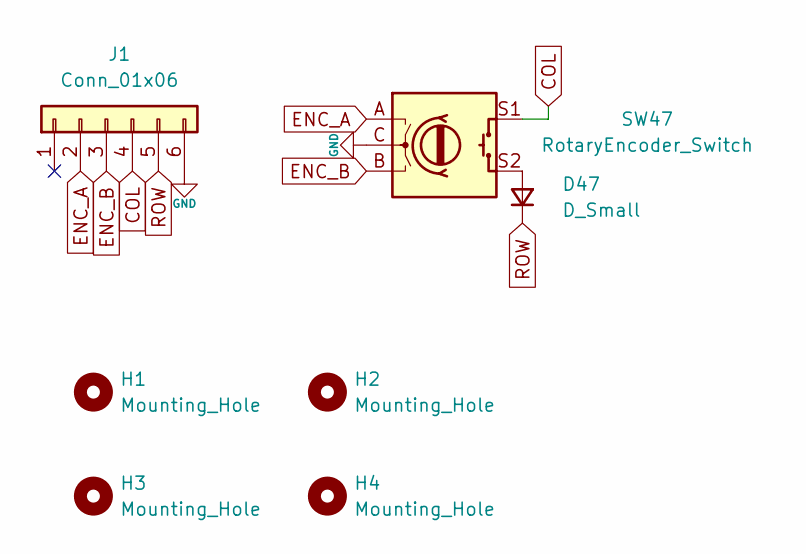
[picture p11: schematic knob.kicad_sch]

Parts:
D47: D_Small; D_SOD-123
H1, H2, H3, H4: Mounting_Hole; Standoff_M2x6mm
J1: Conn_01x06; Hirose_FH12-6S-0.5SH_1x06-1MP_P0.50mm_Horizontal
SW47: RotaryEncoder_Switch; Encoder_EC11_MX

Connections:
COL: J1.4, SW47.S1
ENC_A: J1.2, SW47.A
ENC_B: J1.3, SW47.B
GND: J1.6, SW47.C
unnamed: D47.2 (A), SW47.S2
ROW: D47.1 (K), J1.5

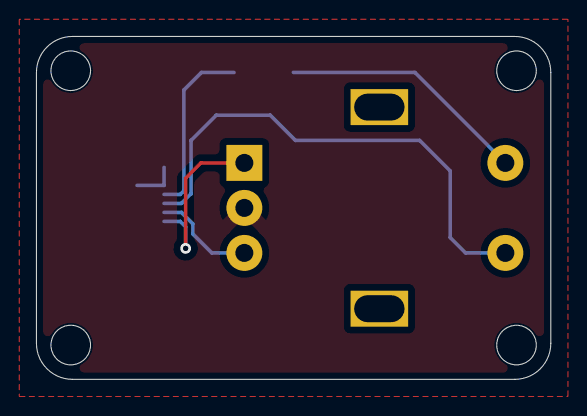
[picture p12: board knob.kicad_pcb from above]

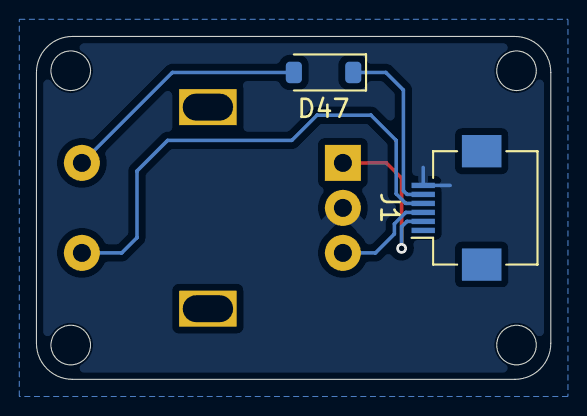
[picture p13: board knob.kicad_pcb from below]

Board: 2 copper layers, 28.6 x 19.1 mm, 7 parts (2 on the bottom side), 6 nets.

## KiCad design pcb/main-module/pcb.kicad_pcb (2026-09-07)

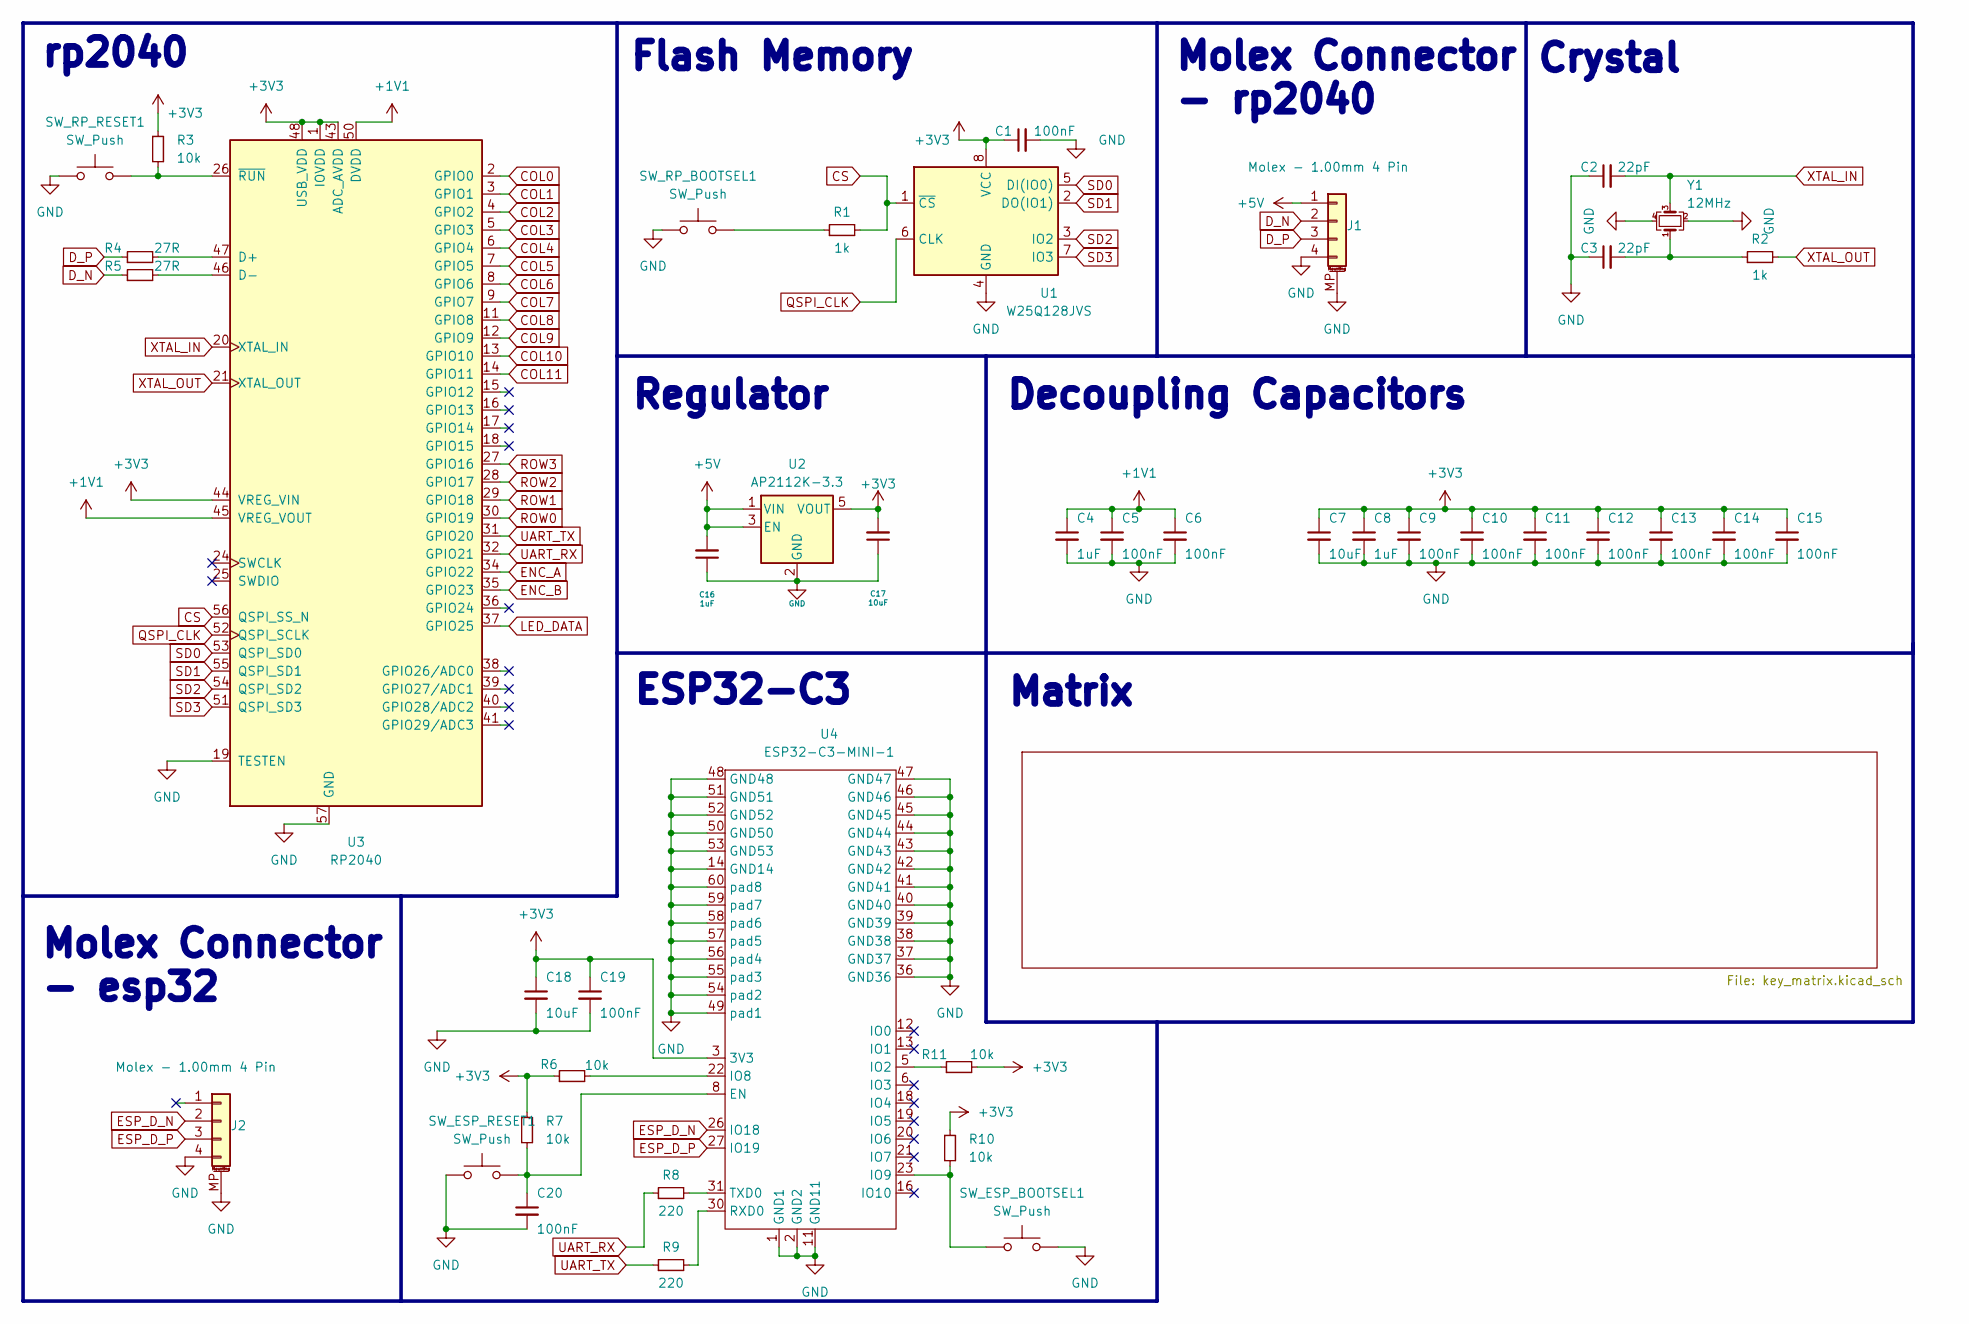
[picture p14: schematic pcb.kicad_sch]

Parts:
C1, C5, C6, C9, C10, C11, C12, C13, C14, C15: 100nF; C_0402_1005Metric; LCSC C66501
C2, C3: 22pF; C_0402_1005Metric; LCSC C1653
C4, C8, C16: 1uF; C_0402_1005Metric; LCSC C5673
C7: 10uF; C_0402_1005Metric; LCSC C1691
C17: 10uF; C_0402_1005Metric; LCSC C19702
C18: 10uF; C_0402_1005Metric; LCSC C15525
C19, C20: 100nF; C_0402_1005Metric; LCSC C1525
J1: Molex - 1.00mm 4 Pin; Molex_Pico-EZmate_78171-0004_1x04-1MP_P1.20mm_Vertical; LCSC C588524
J2: Molex - 1.00mm 4 Pin; Molex_Pico-EZmate_78171-0004_1x04-1MP_P1.20mm_Vertical; LCSC C160404
R1, R2: 1k; R_0402_1005Metric; LCSC C21190
R3: 10k; R_0402_1005Metric; LCSC C25804
R4, R5: 27R; R_0402_1005Metric; LCSC C25190
R6, R7, R10, R11: 10k; R_0402_1005Metric; LCSC C11702
R8, R9: 220; R_0402_1005Metric
SW_ESP_BOOTSEL1: SW_Push; SW_SPST_TS-1088-xR020
SW_ESP_RESET1: SW_Push; SW_SPST_TS-1088-xR020
SW_RP_BOOTSEL1: SW_Push; SW_SPST_TS-1088-xR020
SW_RP_RESET1: SW_Push; SW_SPST_TS-1088-xR020
U1: W25Q128JVS; SOIC-8_5.3x5.3mm_P1.27mm; LCSC C131025
U2: AP2112K-3.3; SOT-23-5
U3: RP2040; RP2040-QFN-56; LCSC C2040
U4: ESP32-C3-MINI-1; LCSC C41349510
Y1: 12MHz; Crystal_SMD_3225-4Pin_3.2x2.5mm; LCSC C9002

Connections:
+1V1: C4.1, C5.1, C6.1, U3.23 (DVDD), U3.45 (VREG_VOUT), U3.50 (DVDD)
+3V3: C1.1, C7.1, C8.1, C9.1, C10.1, C11.1, C12.1, C13.1, C14.1, C15.1, C17.2, C18.1, C19.1, R3.1, R6.1, R7.1, R10.1, R11.2, U1.8 (VCC), U2.5 (VOUT), U3.1 (IOVDD), U3.10 (IOVDD), U3.22 (IOVDD), U3.33 (IOVDD), U3.42 (IOVDD), U3.43 (ADC_AVDD), U3.44 (VREG_VIN), U3.48 (USB_VDD), U3.49 (IOVDD), U4.3 (3V3); also elsewhere on the board
+5V: C16.2, J1.1, U2.1 (VIN), U2.3 (EN)
COL0: U3.2 (GPIO0); also elsewhere on the board
COL1: U3.3 (GPIO1); also elsewhere on the board
COL2: U3.4 (GPIO2); also elsewhere on the board
COL3: U3.5 (GPIO3); also elsewhere on the board
COL4: U3.6 (GPIO4); also elsewhere on the board
COL5: U3.7 (GPIO5); also elsewhere on the board
COL6: U3.8 (GPIO6); also elsewhere on the board
COL7: U3.9 (GPIO7); also elsewhere on the board
COL8: U3.11 (GPIO8); also elsewhere on the board
COL9: U3.12 (GPIO9); also elsewhere on the board
COL10: U3.13 (GPIO10); also elsewhere on the board
COL11: U3.14 (GPIO11); also elsewhere on the board
CS: R1.2, U1.1 (~CS), U3.56 (QSPI_SS_N)
D_N: J1.2, R5.1
D_P: J1.3, R4.1
ENC_A: U3.34 (GPIO22); also elsewhere on the board
ENC_B: U3.35 (GPIO23); also elsewhere on the board
ESP_D_N: J2.2, U4.26 (IO18)
ESP_D_P: J2.3, U4.27 (IO19)
GND: C1.2, C2.1, C3.1, C4.2, C5.2, C6.2, C7.2, C8.2, C9.2, C10.2, C11.2, C12.2, C13.2, C14.2, C15.2, C16.1, C17.1, C18.2, C19.2, C20.2, J1.4, J1.MP (MountPin), J2.4, J2.MP (MountPin), SW_ESP_BOOTSEL1.2, SW_ESP_RESET1.1, SW_RP_BOOTSEL1.1, SW_RP_RESET1.1, U1.4 (GND), U2.2 (GND), U3.19 (TESTEN), U3.57 (GND), U4.1 (GND1), U4.2 (GND2), U4.11 (GND11), U4.14 (GND14), U4.36 (GND36), U4.37 (GND37), U4.38 (GND38), U4.39 (GND39), U4.40 (GND40), U4.41 (GND41), U4.42 (GND42), U4.43 (GND43), U4.44 (GND44), U4.45 (GND45), U4.46 (GND46), U4.47 (GND47), U4.48 (GND48), U4.49 (pad1), U4.50 (GND50), U4.51 (GND51), U4.52 (GND52), U4.53 (GND53), U4.54 (pad2), U4.55 (pad3), U4.56 (pad4), U4.57 (pad5), U4.58 (pad6), U4.59 (pad7), U4.60 (pad8), Y1.2, Y1.4; also elsewhere on the board
LED_DATA: U3.37 (GPIO25); also elsewhere on the board
unnamed: C3.2, R2.1, Y1.1
unnamed: R1.1, SW_RP_BOOTSEL1.2
unnamed: R4.2, U3.47 (D+)
unnamed: R5.2, U3.46 (D-)
unnamed: R3.2, SW_RP_RESET1.2, U3.26 (~RUN)
unnamed: C20.1, R7.2, SW_ESP_RESET1.2, U4.8 (EN)
unnamed: R11.1, U4.5 (IO2)
unnamed: R6.2, U4.22 (IO8)
unnamed: R10.2, SW_ESP_BOOTSEL1.1, U4.23 (IO9)
unnamed: R9.2, U4.30 (RXD0)
unnamed: R8.2, U4.31 (TXD0)
QSPI_CLK: U1.6 (CLK), U3.52 (QSPI_SCLK)
ROW0: U3.30 (GPIO19); also elsewhere on the board
ROW1: U3.29 (GPIO18); also elsewhere on the board
ROW2: U3.28 (GPIO17); also elsewhere on the board
ROW3: U3.27 (GPIO16); also elsewhere on the board
SD0: U1.5 (DI(IO0)), U3.53 (QSPI_SD0)
SD1: U1.2 (DO(IO1)), U3.55 (QSPI_SD1)
SD2: U1.3 (IO2), U3.54 (QSPI_SD2)
SD3: U1.7 (IO3), U3.51 (QSPI_SD3)
UART_RX: R8.1, U3.32 (GPIO21)
UART_TX: R9.1, U3.31 (GPIO20)
XTAL_IN: C2.2, U3.20 (XTAL_IN), Y1.3
XTAL_OUT: R2.2, U3.21 (XTAL_OUT)

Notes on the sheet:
Molex Connector - rp2040
Decoupling Capacitors
Regulator
rp2040
Crystal
ESP32-C3
Molex Connector - esp32
Flash Memory
Matrix

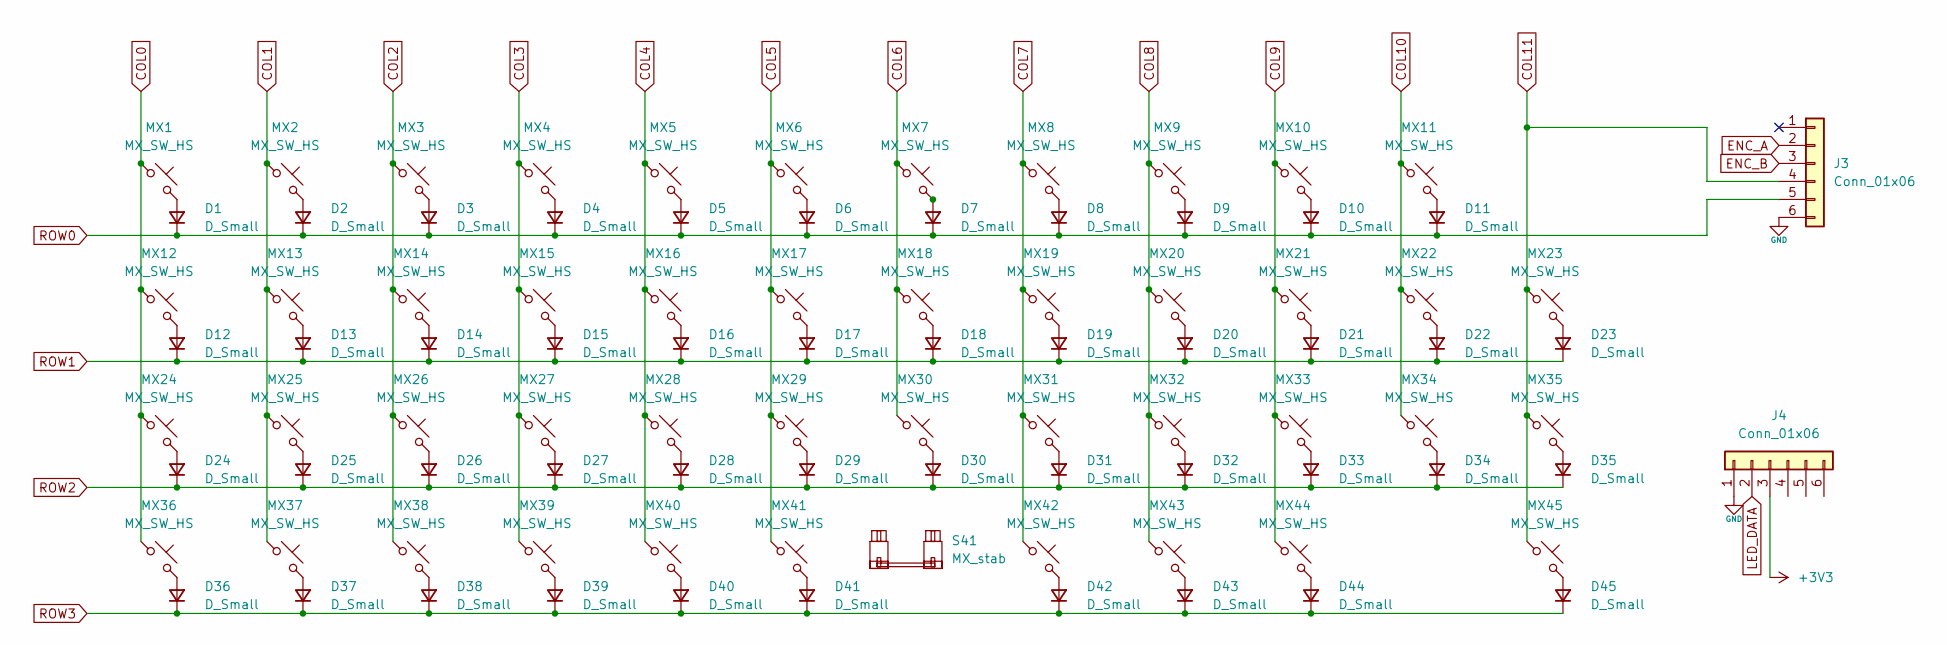
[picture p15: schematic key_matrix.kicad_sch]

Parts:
D1, D2, D3, D4, D5, D6, D7, D8, D9, D10, D11, D12, D13, D14, D15, D16, D17, D18, D19, D20, D21, D22, D23, D24, D25, D26, D27, D28, D29, D30, D31, D32, D33, D34, D35, D36, D37, D38, D39, D40, D41, D42, D43, D44, D45: D_Small; D_SOD-123
J3, J4: Conn_01x06; Hirose_FH12-6S-0.5SH_1x06-1MP_P0.50mm_Horizontal
MX1, MX2, MX3, MX4, MX5, MX6, MX7, MX8, MX9, MX10, MX11, MX12, MX13, MX14, MX15, MX16, MX17, MX18, MX19, MX20, MX21, MX22, MX23, MX24, MX25, MX26, MX27, MX28, MX29, MX30, MX31, MX32, MX33, MX34, MX35, MX36, MX37, MX38, MX39, MX40, MX41, MX42, MX43, MX44, MX45: MX_SW_HS; SW_MX_HS_CPG151101S11_1u
S41: MX_stab; STAB_MX_P_2u

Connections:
+3V3: J4.3; also elsewhere on the board
COL0: MX1.1, MX12.1, MX24.1, MX36.1; also elsewhere on the board
COL1: MX2.1, MX13.1, MX25.1, MX37.1; also elsewhere on the board
COL2: MX3.1, MX14.1, MX26.1, MX38.1; also elsewhere on the board
COL3: MX4.1, MX15.1, MX27.1, MX39.1; also elsewhere on the board
COL4: MX5.1, MX16.1, MX28.1, MX40.1; also elsewhere on the board
COL5: MX6.1, MX17.1, MX29.1, MX41.1; also elsewhere on the board
COL6: MX7.1, MX18.1, MX30.1; also elsewhere on the board
COL7: MX8.1, MX19.1, MX31.1, MX42.1; also elsewhere on the board
COL8: MX9.1, MX20.1, MX32.1, MX43.1; also elsewhere on the board
COL9: MX10.1, MX21.1, MX33.1, MX44.1; also elsewhere on the board
COL10: MX11.1, MX22.1, MX34.1; also elsewhere on the board
COL11: J3.4, MX23.1, MX35.1, MX45.1; also elsewhere on the board
ENC_A: J3.2; also elsewhere on the board
ENC_B: J3.3; also elsewhere on the board
GND: J3.6, J4.1; also elsewhere on the board
LED_DATA: J4.2; also elsewhere on the board
unnamed: D1.2 (A), MX1.2
unnamed: D2.2 (A), MX2.2
unnamed: D3.2 (A), MX3.2
unnamed: D4.2 (A), MX4.2
unnamed: D5.2 (A), MX5.2
unnamed: D6.2 (A), MX6.2
unnamed: D7.2 (A), MX7.2
unnamed: D8.2 (A), MX8.2
unnamed: D9.2 (A), MX9.2
unnamed: D10.2 (A), MX10.2
unnamed: D11.2 (A), MX11.2
unnamed: D12.2 (A), MX12.2
unnamed: D13.2 (A), MX13.2
unnamed: D14.2 (A), MX14.2
unnamed: D15.2 (A), MX15.2
unnamed: D16.2 (A), MX16.2
unnamed: D17.2 (A), MX17.2
unnamed: D18.2 (A), MX18.2
unnamed: D19.2 (A), MX19.2
unnamed: D20.2 (A), MX20.2
unnamed: D21.2 (A), MX21.2
unnamed: D22.2 (A), MX22.2
unnamed: D23.2 (A), MX23.2
unnamed: D24.2 (A), MX24.2
unnamed: D25.2 (A), MX25.2
unnamed: D26.2 (A), MX26.2
unnamed: D27.2 (A), MX27.2
unnamed: D28.2 (A), MX28.2
unnamed: D29.2 (A), MX29.2
unnamed: D30.2 (A), MX30.2
unnamed: D31.2 (A), MX31.2
unnamed: D32.2 (A), MX32.2
unnamed: D33.2 (A), MX33.2
unnamed: D34.2 (A), MX34.2
unnamed: D35.2 (A), MX35.2
unnamed: D36.2 (A), MX36.2
unnamed: D37.2 (A), MX37.2
unnamed: D38.2 (A), MX38.2
unnamed: D39.2 (A), MX39.2
unnamed: D40.2 (A), MX40.2
unnamed: D41.2 (A), MX41.2
unnamed: D42.2 (A), MX42.2
unnamed: D43.2 (A), MX43.2
unnamed: D44.2 (A), MX44.2
unnamed: D45.2 (A), MX45.2
ROW0: D1.1 (K), D2.1 (K), D3.1 (K), D4.1 (K), D5.1 (K), D6.1 (K), D7.1 (K), D8.1 (K), D9.1 (K), D10.1 (K), D11.1 (K), J3.5; also elsewhere on the board
ROW1: D12.1 (K), D13.1 (K), D14.1 (K), D15.1 (K), D16.1 (K), D17.1 (K), D18.1 (K), D19.1 (K), D20.1 (K), D21.1 (K), D22.1 (K), D23.1 (K); also elsewhere on the board
ROW2: D24.1 (K), D25.1 (K), D26.1 (K), D27.1 (K), D28.1 (K), D29.1 (K), D30.1 (K), D31.1 (K), D32.1 (K), D33.1 (K), D34.1 (K), D35.1 (K); also elsewhere on the board
ROW3: D36.1 (K), D37.1 (K), D38.1 (K), D39.1 (K), D40.1 (K), D41.1 (K), D42.1 (K), D43.1 (K), D44.1 (K), D45.1 (K); also elsewhere on the board

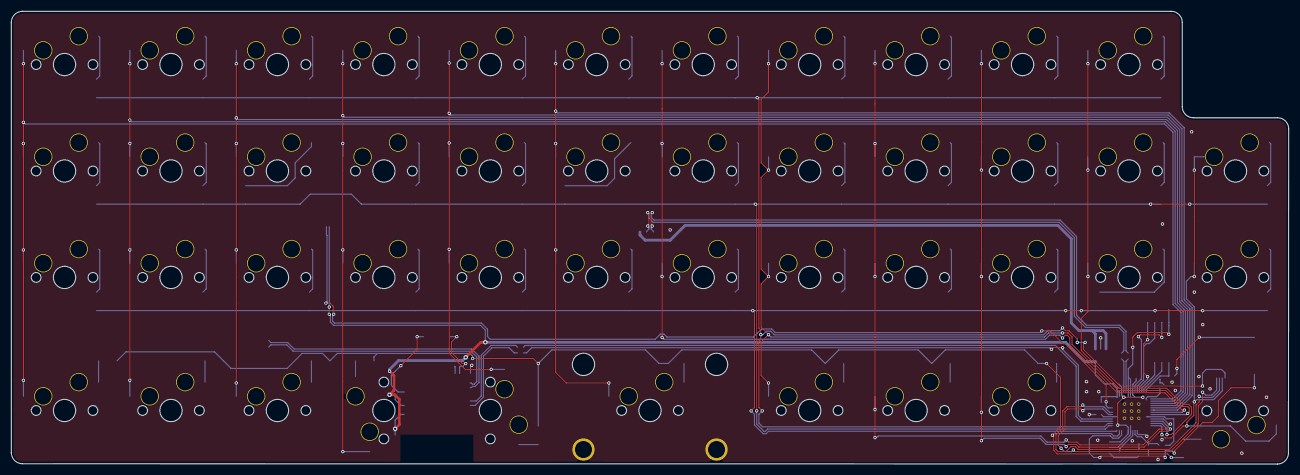
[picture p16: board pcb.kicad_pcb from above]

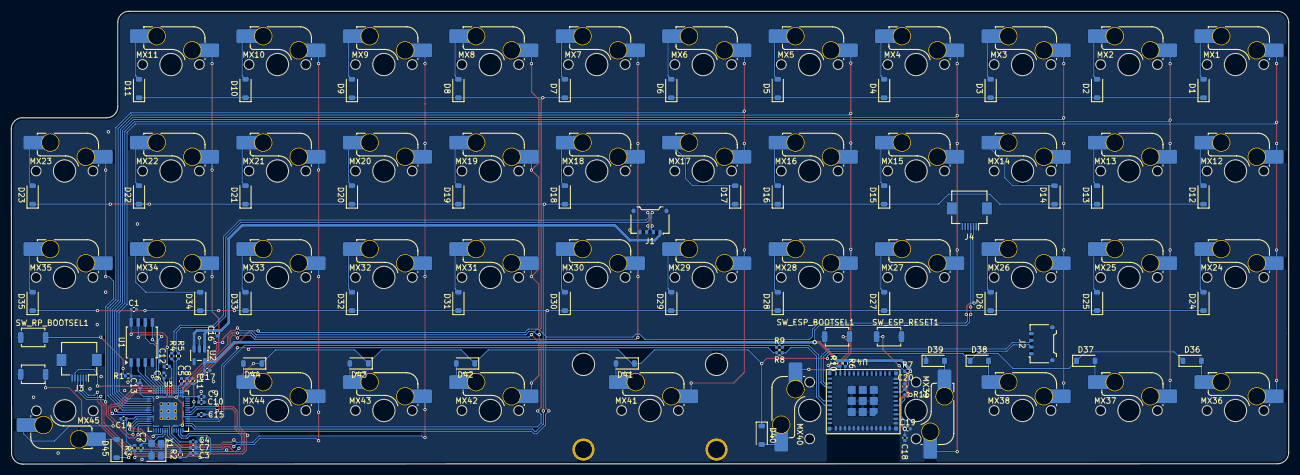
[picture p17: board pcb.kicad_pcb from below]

Board: 2 copper layers, 228.6 x 81.0 mm, 135 parts (134 on the bottom side), 93 nets.

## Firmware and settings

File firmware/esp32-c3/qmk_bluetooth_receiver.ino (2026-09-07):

#include <Arduino.h>
#include <NimBLEDevice.h>
#include <NimBLEHIDDevice.h>
#include <Preferences.h>
#include <string>
#include <string.h>

#define DEVICE_NAME "Ostinato"
#define MANUFACTURER_NAME "sky2park"

#define UART_RX_PIN 20
#define UART_TX_PIN 21
#define UART_BAUD 115200

#define FRAME_HEADER 0xAA
#define EVENT_PRESS 0x01
#define EVENT_RELEASE 0x00
#define CMD_SELECT_BT_SLOT 0x10
#define CMD_CLEAR_BT_SLOT 0x11

#define BT_SLOT_NONE 0x00
#define BT_SLOT_1 0x01
#define BT_SLOT_2 0x02
#define BT_SLOT_3 0x03
#define BT_SLOT_COUNT 3

#define STATUS_BT 0x80

#define BT_STATE_OFF 0x00
#define BT_STATE_ADVERTISING 0x01
#define BT_STATE_CONNECTED 0x02
#define BT_STATE_PAIRING 0x03
#define BT_STATE_ERROR 0x04

#define DEBUG_UART_RX 0

#define REPORT_ID_KEYBOARD 0x01
#define MAX_KEYS 6

struct KeyboardReport {
  uint8_t modifiers;
  uint8_t reserved;
  uint8_t keys[MAX_KEYS];
} __attribute__((packed));


static uint8_t hidReportMap[] = {
  0x05, 0x01,
  0x09, 0x06,
  0xA1, 0x01,
  0x85, REPORT_ID_KEYBOARD,

  0x05, 0x07,
  0x19, 0xE0,
  0x29, 0xE7,
  0x15, 0x00,
  0x25, 0x01,
  0x75, 0x01,
  0x95, 0x08,
  0x81, 0x02,

  0x95, 0x01,
  0x75, 0x08,
  0x81, 0x01,

  0x95, 0x05,
  0x75, 0x01,
  0x05, 0x08,
  0x19, 0x01,
  0x29, 0x05,
  0x91, 0x02,

  0x95, 0x01,
  0x75, 0x03,
  0x91, 0x01,

  0x95, 0x06,
  0x75, 0x08,
  0x15, 0x00,
  0x26, 0xFF, 0x00,
  0x05, 0x07,
  0x19, 0x00,
  0x29, 0xFF,
  0x81, 0x00,

  0xC0
};

HardwareSerial KeyboardUart(1);

NimBLEServer *server = nullptr;
NimBLEHIDDevice *hid = nullptr;
NimBLECharacteristic *keyboardInput = nullptr;

struct SlotPeer {
  bool valid;
  NimBLEAddress address;
};

KeyboardReport report = {0, 0, {0, 0, 0, 0, 0, 0}};
SlotPeer slotPeers[BT_SLOT_COUNT + 1];
bool connected = false;
uint16_t activeConnHandle = 0;
uint8_t activeSlot = BT_SLOT_NONE;
uint8_t pairingSlot = BT_SLOT_NONE;
uint8_t lastStatusSlot = 0xFF;
uint8_t lastStatusState = 0xFF;

bool isModifier(uint8_t keycode) {
  return keycode >= 0xE0 && keycode <= 0xE7;
}

void sendReport() {
  if (!connected || keyboardInput == nullptr) {
    return;
  }

  const uint8_t *data = reinterpret_cast<const uint8_t *>(&report);
  keyboardInput->setValue(data, sizeof(report));
  keyboardInput->notify(data, sizeof(report));
}

void sendBtStatus(uint8_t slot, uint8_t state) {
  if (lastStatusSlot == slot && lastStatusState == state) {
    return;
  }

  lastStatusSlot = slot;
  lastStatusState = state;

  KeyboardUart.write(FRAME_HEADER);
  KeyboardUart.write(STATUS_BT);
  KeyboardUart.write((slot << 4) | (state & 0x0F));

  Serial.print("TX status: slot=");
  Serial.print(slot);
  Serial.print(" state=");
  Serial.println(state);
}

void clearKeys() {
  memset(&report, 0, sizeof(report));
  sendReport();
}

bool isBtSlot(uint8_t slot) {
  return slot >= BT_SLOT_1 && slot <= BT_SLOT_3;
}

void makeSlotKeys(uint8_t slot, char *addressKey, size_t addressKeySize, char *typeKey, size_t typeKeySize) {
  snprintf(addressKey, addressKeySize, "slot%u", slot);
  snprintf(typeKey, typeKeySize, "type%u", slot);
}

void loadSlotPeers() {
  Preferences prefs;

  if (!prefs.begin("bt_slots", false)) {
    Serial.println("Preferences open failed for load");
    return;
  }

  for (uint8_t slot = BT_SLOT_1; slot <= BT_SLOT_3; slot++) {
    char addressKey[8];
    char typeKey[8];
    makeSlotKeys(slot, addressKey, sizeof(addressKey), typeKey, sizeof(typeKey));

    String address = prefs.getString(addressKey, "");
    uint8_t type = prefs.getUChar(typeKey, 0);

    slotPeers[slot].valid = address.length() > 0;
    if (slotPeers[slot].valid) {
      slotPeers[slot].address = NimBLEAddress(std::string(address.c_str()), type);

      Serial.print("Loaded BT slot ");
      Serial.print(slot);
      Serial.print(": ");
      Serial.println(address);
    } else {
      Serial.print("Loaded BT slot ");
      Serial.print(slot);
      Serial.println(": empty");
    }
  }
}

void saveSlotPeer(uint8_t slot, const NimBLEAddress &address) {
  if (!isBtSlot(slot) || address.isNull()) {
    return;
  }

  Preferences prefs;

  if(!prefs.begin("bt_slots", false)) {
    Serial.println("Preferences open failed for save");
    return;
  }

  char addressKey[8];
  char typeKey[8];
  makeSlotKeys(slot, addressKey, sizeof(addressKey), typeKey, sizeof(typeKey));

  String addressText = String(address.toString().c_str());
  uint8_t type = address.getType();

  size_t addressBytes = prefs.putString(addressKey, addressText);
  size_t typeBytes = prefs.putUChar(typeKey, type);

  String readBackAddress = prefs.getString(addressKey, "");
  uint8_t readBackType = prefs.getUChar(typeKey, 0);

  prefs.end();

  slotPeers[slot].valid = readBackAddress.length() > 0;
  if(slotPeers[slot].valid) {
    slotPeers[slot].address = NimBLEAddress(std::string(readBackAddress.c_str()), readBackType);
  }

  Serial.print("BT slot ");
  Serial.print(slot);
  Serial.print(": ");
  Serial.println(addressText);
  
  Serial.print("Saved bytes address/type: ");
  Serial.print(addressBytes);
  Serial.print("/");
  Serial.println(typeBytes);

  Serial.print("Read back slot ");
  Serial.print(slot);
  Serial.print(": ");
  Serial.print(readBackAddress);
  Serial.print(" type=");
  Serial.println(readBackType);
}

uint8_t findSlotByPeer(NimBLEConnInfo &connInfo) {
  NimBLEAddress idAddress = connInfo.getIdAddress();
  NimBLEAddress otaAddress = connInfo.getAddress();

  for (uint8_t slot = BT_SLOT_1; slot <= BT_SLOT_3; slot++) {
    if (!slotPeers[slot].valid) {
      continue;
    }
    
    if (slotPeers[slot].address == idAddress || slotPeers[slot].address == otaAddress) {
      return slot;
    }
  }

  return BT_SLOT_NONE;
}

void clearWhiteList() {
  while (NimBLEDevice::getWhiteListCount() > 0) {
    NimBLEDevice::whiteListRemove(NimBLEDevice::getWhiteListAddress(0));
  }
}

void startAdvertisingForActiveSlot() {
  NimBLEAdvertising *advertising = NimBLEDevice::getAdvertising();

  NimBLEDevice::stopAdvertising();
  clearWhiteList();

  if (activeSlot == BT_SLOT_NONE || !isBtSlot(activeSlot)) {
    return;
  }

  if (slotPeers[activeSlot].valid && pairingSlot != activeSlot) {
    NimBLEDevice::whiteListAdd(slotPeers[activeSlot].address);
    advertising->setScanFilter(false, true);
    Serial.print("BLE advertising whitelist slot ");
    Serial.println(activeSlot);
    sendBtStatus(activeSlot, BT_STATE_ADVERTISING);
  } else {
    advertising->setScanFilter(false, false);
    Serial.println("BLE advertising open");
    sendBtStatus(activeSlot, BT_STATE_PAIRING);
  }

  advertising->start();
  
}

bool peerMatchesSlot(uint8_t slot, NimBLEConnInfo &connInfo) {
  if (!isBtSlot(slot) || !slotPeers[slot].valid) {
    return false;
  }

  NimBLEAddress idAddress = connInfo.getIdAddress();
  NimBLEAddress otaAddress = connInfo.getAddress();

  return slotPeers[slot].address == idAddress || slotPeers[slot].address == otaAddress;
}

NimBLEAddress preferredPeerAddress(NimBLEConnInfo &connInfo) {
  NimBLEAddress idAddress = connInfo.getIdAddress();

  if (!idAddress.isNull()) {
    return idAddress;
  }

  return connInfo.getAddress();
}

void clearBtSlot(uint8_t slot) {
  if (!isBtSlot(slot)) {
    return;
  }

  if (slotPeers[slot].valid) {
    NimBLEDevice::deleteBond(slotPeers[slot].address);
  }

  char addressKey[8];
  char typeKey[8];
  makeSlotKeys(slot, addressKey, sizeof(addressKey), typeKey, sizeof(typeKey));

  Preferences prefs;
  if (prefs.begin("bt_slots", false)) {
    prefs.remove(addressKey);
    prefs.remove(typeKey);
    prefs.end();
  } else {
    Serial.println("Preferences open failed for clear");
  }
  slotPeers[slot].valid = false;
  slotPeers[slot].address = NimBLEAddress();

  if(activeSlot == slot) {
    clearKeys();
    activeSlot = BT_SLOT_NONE;
    pairingSlot = BT_SLOT_NONE;
    NimBLEDevice::stopAdvertising();

    if (connected && server != nullptr) {
      server->disconnect(activeConnHandle);
    }
  }

  Serial.print("BT slot cleared: ");
  Serial.println(slot);
}

void selectBtSlot(uint8_t slot) {
  if (slot != BT_SLOT_NONE && !isBtSlot(slot)) {
    return;
  }

  if(activeSlot == slot && slot != BT_SLOT_NONE) {
    if (!connected) {
      startAdvertisingForActiveSlot();
    }
    return;
  }

  clearKeys();
  activeSlot = slot;

  if (activeSlot == BT_SLOT_NONE) {
    pairingSlot = BT_SLOT_NONE;
    NimBLEDevice::stopAdvertising();
    clearWhiteList();

    if (connected && server != nullptr) {
      Serial.println("Disconnecting current BLE connection");
      server->disconnect(activeConnHandle);
    }

    Serial.println("BT slot none");
    sendBtStatus(BT_SLOT_NONE, BT_STATE_OFF);
    return;
  }

  if (!slotPeers[activeSlot].valid) {
    pairingSlot = activeSlot;
    Serial.print("BT slot ");
    Serial.print(activeSlot);
    Serial.println(" is empty; pairing mode");
    sendBtStatus(activeSlot, BT_STATE_PAIRING);
  } else {
    pairingSlot = BT_SLOT_NONE;
    Serial.print("BT slot selected: ");
    Serial.println(activeSlot);
    sendBtStatus(activeSlot, BT_STATE_ADVERTISING);
  }

  if (connected && server != nullptr) {
    Serial.println("Disconnecting current BLE connection");
    server->disconnect(activeConnHandle);
    return;
  }

  startAdvertisingForActiveSlot();
}

void pressKey(uint8_t keycode) {
  if (keycode == 0x00) {
    return;
  }
  
  if (isModifier(keycode)) {
    report.modifiers |= 1 << (keycode - 0xE0);
    sendReport();
    return;
  }

  for(uint8_t i = 0; i < MAX_KEYS; i++) {
    if (report.keys[i] == keycode) {
      sendReport();
      return;
    }
  }

  for(uint8_t i = 0; i < MAX_KEYS; i++) {
    if(report.keys[i] == 0x00) {
      report.keys[i] = keycode;
      sendReport();
      return;
    }
  }

  //more than 6 normal keys are ignored by this simple keyboard report.
}

void releaseKey(uint8_t keycode) {
  if (keycode == 0x00) {
    return;
  }
  
  if (isModifier(keycode)) {
    report.modifiers &= ~(1 << (keycode - 0xE0));
    sendReport();
    return;
  }

  for(uint8_t i = 0; i < MAX_KEYS; i++) {
    if (report.keys[i] == keycode) {
      report.keys[i] = 0x00;
    }
  }

  sendReport();
}

bool readFrame(uint8_t &eventType, uint8_t &keycode) {
  static uint8_t state = 0;
  static uint8_t event = 0;

  while (KeyboardUart.available() > 0) {
    uint8_t b = static_cast<uint8_t>(KeyboardUart.read());

#if DEBUG_UART_RX
    Serial.print("RX byte: 0x");
    if(b < 0x10) {
      Serial.print("0");
    }
    Serial.println(b, HEX);
#endif

    if (state == 0) {
      if (b == FRAME_HEADER) {
        state = 1;
      }
    } else if (state == 1) {
      if (b == EVENT_PRESS || b == EVENT_RELEASE || b == CMD_SELECT_BT_SLOT || b == CMD_CLEAR_BT_SLOT) {
        event = b;
        state = 2;
      } else if(b != FRAME_HEADER) {
        state = 0;
      }
    } else {
      eventType = event;
      keycode = b;
      state = 0;
      return true;
    }
  }

  return false;
}

class ServerCallbacks : public NimBLEServerCallbacks {
  void onConnect(NimBLEServer *server, NimBLEConnInfo &connInfo) override {
    connected = true;
    activeConnHandle = connInfo.getConnHandle();
    memset(&report, 0, sizeof(report));
    server->updateConnParams(connInfo.getConnHandle(), 12, 24, 0, 200);

    Serial.println("BLE Connected");

    if(activeSlot == BT_SLOT_NONE || !isBtSlot(activeSlot)) {
      Serial.println("No active BT slot; disconnecting");
      server->disconnect(connInfo);
      return;
    }

    if (pairingSlot == activeSlot) {
      Serial.println("Pairing mode connection accepted");
      sendBtStatus(activeSlot, BT_STATE_CONNECTED);
      return;
    }

    if(pairingSlot != activeSlot && slotPeers[activeSlot].valid && !peerMatchesSlot(activeSlot, connInfo)) {
      Serial.println("Connected peer does not match selected slot; disconnecting");
      sendBtStatus(activeSlot, BT_STATE_ERROR);
      server->disconnect(connInfo);
      return;
    }

    sendBtStatus(activeSlot, BT_STATE_CONNECTED);
  }
  
  void onDisconnect(NimBLEServer *server, NimBLEConnInfo &connInfo, int reason) override {
    connected = false;
    activeConnHandle = 0;
    memset(&report, 0, sizeof(report));
    Serial.println("BLE disconnected, advertising again");

    if(activeSlot != BT_SLOT_NONE) {
      startAdvertisingForActiveSlot();
    }
  }

  void onAuthenticationComplete(NimBLEConnInfo &connInfo) override {
    if (!connInfo.isBonded()) {
      Serial.println("BLE authentication failed of not bonded; disconnecting");
      
      if (server != nullptr) {
        server->disconnect(connInfo.getConnHandle());
      }

      return;
    }

    if (isBtSlot(pairingSlot)) {
      uint8_t existingSlot = findSlotByPeer(connInfo);

      if (existingSlot != BT_SLOT_NONE && existingSlot != pairingSlot) {
        Serial.print("Peer already saved in BT slot ");
        Serial.print(existingSlot);
        Serial.println("; disconnecting");

        if (server != nullptr) {
          server->disconnect(connInfo);
        }

        return;
      }

      saveSlotPeer(pairingSlot, preferredPeerAddress(connInfo));
      pairingSlot = BT_SLOT_NONE;
    }
  }

  void onIdentity(NimBLEConnInfo &connInfo) override {
    if (isBtSlot(pairingSlot) && connInfo.isBonded()) {
      uint8_t existingSlot = findSlotByPeer(connInfo);

      if (existingSlot != BT_SLOT_NONE && existingSlot != pairingSlot) {
        Serial.print("Peer already saved in BT slot ");
        Serial.print(existingSlot);
        Serial.println("; disconnecting");

        if (server != nullptr) {
          server->disconnect(connInfo);
        }

        return;
      }

      saveSlotPeer(pairingSlot, preferredPeerAddress(connInfo));
      pairingSlot = BT_SLOT_NONE;
    }
  }
};

ServerCallbacks callbacks;

void setupBle() {
  NimBLEDevice::init(DEVICE_NAME);
  NimBLEDevice::setSecurityIOCap(BLE_HS_IO_NO_INPUT_OUTPUT);
  NimBLEDevice::setSecurityAuth(true, false, true);

  server = NimBLEDevice::createServer();
  server->setCallbacks(&callbacks, false);

  hid = new NimBLEHIDDevice(server);
  keyboardInput = hid->getInputReport(REPORT_ID_KEYBOARD);

  hid->setManufacturer(MANUFACTURER_NAME);
  hid->setPnp(0x02, 0xCafe, 0x4001, 0x0100);
  hid->setHidInfo(0x00, 0x01);
  hid->setReportMap(hidReportMap, sizeof(hidReportMap));
  hid->setBatteryLevel(100);

  server->start();

  NimBLEAdvertising *advertising = NimBLEDevice::getAdvertising();
  advertising->setName(DEVICE_NAME);
  advertising->setAppearance(HID_KEYBOARD);
  advertising->addServiceUUID(hid->getHidService()->getUUID());
  advertising->enableScanResponse(true);
  if(activeSlot != BT_SLOT_NONE) {
    startAdvertisingForActiveSlot();
  }
}

void setup() {
  Serial.begin(115200);
  delay(300);

  KeyboardUart.begin(UART_BAUD, SERIAL_8N1, UART_RX_PIN, UART_TX_PIN);
  loadSlotPeers();
  setupBle();
  
  Serial.println("UART to BLE HID keyboard ready");
}

void loop() {
  uint8_t eventType;
  uint8_t keycode;

  while (readFrame(eventType, keycode)) {
    if (eventType == EVENT_PRESS) {
      if(activeSlot != BT_SLOT_NONE) {
        pressKey(keycode);
      }
    } else if(eventType == EVENT_RELEASE) {
      if(activeSlot != BT_SLOT_NONE) {
        releaseKey(keycode);
      }
    } else if(eventType == CMD_SELECT_BT_SLOT) {
      selectBtSlot(keycode);
    } else if(eventType == CMD_CLEAR_BT_SLOT) {
      clearBtSlot(keycode);
    }
  }

  delay(1);
}

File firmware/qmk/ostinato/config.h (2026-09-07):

#pragma once

// UART 설정 (ESP32C3와의 통신을 위한 핀과 보레이트 정의)
#define UART_DRIVER SIOD1
#define UART_TX_PIN GP20
#define UART_RX_PIN GP21
#define UART_BAUD_RATE 115200

#define ENCODER_A_PINS { GP22 }
#define ENCODER_B_PINS { GP23 }
#define ENCODER_RESOLUTION 2

#define WS2812_DI_PIN GP25
#define WS2812_LED_COUNT 4

#define BOOTMAGIC_ROW 0
#define BOOTMAGIC_COLUMN 0

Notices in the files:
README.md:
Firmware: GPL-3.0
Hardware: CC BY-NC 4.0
